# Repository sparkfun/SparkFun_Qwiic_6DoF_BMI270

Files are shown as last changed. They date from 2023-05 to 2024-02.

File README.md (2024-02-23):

SparkFun Qwiic 6DoF BMI270
========================================

<table class="table table-hover table-striped table-bordered">
    <tr align="center">
        <td><a href="https://www.sparkfun.com/products/22397">SparkFun 6DoF IMU Breakout - BMI270 (Qwiic)</a></td>
        <td><a href="https://www.sparkfun.com/products/22398">SparkFun Micro 6DoF IMU Breakout - BMI270 (Qwiic)</a></td>
    </tr>
    <tr align="center">
        <td><i><a href="https://www.sparkfun.com/products/22397">SparkFun 6DoF IMU Breakout - BMI270 (Qwiic)</a></td></i></td>
        <td><i><a href="https://www.sparkfun.com/products/22398">SparkFun Micro 6DoF IMU Breakout - BMI270 (Qwiic)</a></i></td>
    </tr>
</table>

The SparkFun BMI270 6DoF IMU Breakout is a Qwiic-enabled breakout board based on the ultra-low power BMI270 from Bosch. This chip is a highly integrated, low power IMU optimized for wearables providing precise acceleration, angular rate measurement and intelligent on-chip motion-triggered interrupt features.. Not only does the BMI270 comprise a fast and sensitive accelerometer and gyro pair, but it also contains a number of intelligent, on-chip motion-triggered interrupt features.  

Our Standard-sized 1in. x 1in. Qwiic BMI270 IMU Breakout makes it easy to add this sensor to your project using our solderless Qwiic cables and compatible controllers. If you still prefer to use a breadboard, don't worry, we've still broken out all IO pins to 0.1" spaced pin-headers along the sides of the board. On-board solder jumpers allow you to easily select the device address, remove the I²C pull-ups, and disable the power LED if need be. 

Our Micro-sized 0.3in. x 0.75in. footprint makes this breakout board an ideal option for your smallest projects using our solderless Qwiic cables and compatible controllers. On-board solder jumpers allow you to easily select the device address, remove the I²C pull-ups, and disable the power LED if need be. 

The 6-axis sensor combines a 16-bit tri-axial gyroscope and a 16-bit tri-axial accelerometer featuring Bosch’s automotive-proven gyroscope technology. BMI270 includes several functionalities such as an integrated plug-and-play step counter/detector and gesture detection for wrist-worn devices. Moreover, the IMU is suitable for hearables, smart clothes, smart shoes, smart glasses and ankle bands.

Repository Contents
-------------------

* **/Documentation** - Data sheets, additional product information
* **/Hardware** - Eagle design files (.brd, .sch)
* **/Production** - Production panel files (.brd)

Documentation
--------------
* **[Library](https://github.com/sparkfun/SparkFun_BMI270_Arduino_Library)** - Arduino library for the SparkFun 6DoF IMU Breakout - BMI270 (Qwiic) and SparkFun Micro 6DoF IMU Breakout - BMI270 (Qwiic).
* **[Hookup Guide](http://docs.sparkfun.com/SparkFun_Qwiic_6DoF_BMI270/)** - Basic hookup guide for the SparkFun 6DoF IMU Breakout - BMI270 (Qwiic) and SparkFun Micro 6DoF IMU Breakout - BMI270 (Qwiic). 

License Information
-------------------

This product is _**open source**_! 

Please review the LICENSE.md file for license information. 

If you have any questions or concerns on licensing, please contact technical support on our [SparkFun forums](https://forum.sparkfun.com/viewforum.php?f=152).

Distributed as-is; no warranty is given.

- Your friends at SparkFun.

_<COLLABORATION CREDIT>_

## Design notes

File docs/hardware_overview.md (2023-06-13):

###Accelerometer - BMI270

The ultra-low power BMI270 is an IMU optimized for wearables providing precise acceleration, angular rate measurement and intelligent on-chip motion-triggered interrupt features.

The 6-axis sensor combines a 16-bit tri-axial gyroscope and a 16-bit tri-axial accelerometer featuring Bosch’s automotive-proven gyroscope technology. BMI270 includes several functionalities such as an integrated plug-and-play step counter/detector and gesture detection for wrist-worn devices. Moreover, the IMU is suitable for hearables, smart clothes, smart shoes, smart glasses and ankle bands.

<div class="grid.cards.desc" markdown>

<table class="pdf" style="border-style:none;" markdown="1">
<tbody markdown="1">
<tr markdown="1">
<td align="center" width="35%" markdown="block">
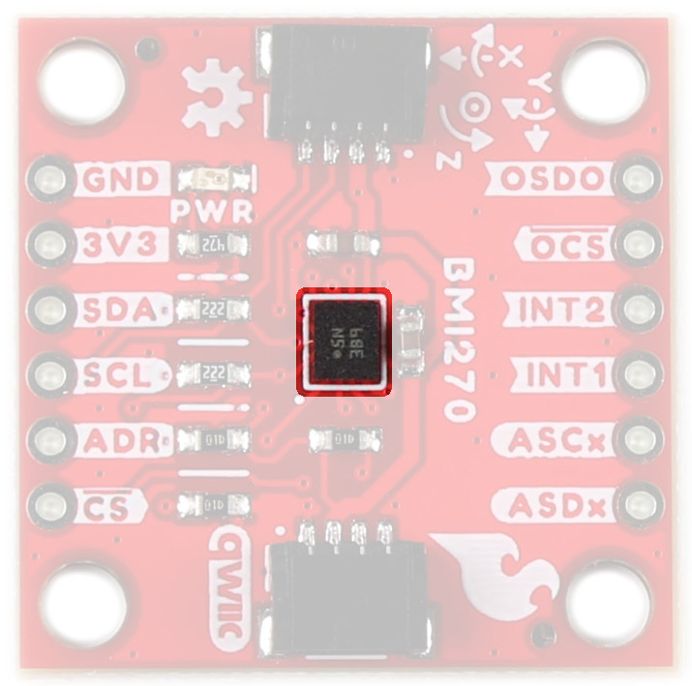
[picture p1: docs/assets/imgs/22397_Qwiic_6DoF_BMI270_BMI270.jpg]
SparkFun 6DoF IMU Breakout - BMI270 (Qwiic)

<figcaption markdown>6DoF BMI270 IC</figcaption>
</td>
<td align="center" width="35%" markdown="block">
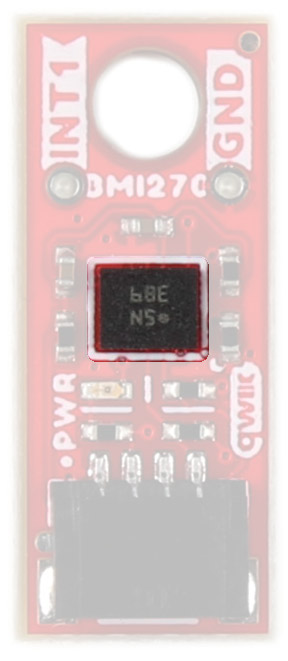
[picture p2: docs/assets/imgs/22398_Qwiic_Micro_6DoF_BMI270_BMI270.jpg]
SparkFun Micro 6DoF IMU Breakout - BMI270 (Qwiic)

<figcaption markdown>Micro 6DoF BMI270 IC</figcaption>
</td>
</tr>
<tr>

</tr>
</tbody>
</table>
</div class>

###Qwiic Connector

The Qwiic connector(s) on the SparkFun 6DoF - BMI270 (Qwiic) and SparkFun 6DoF Micro - BMI270 (Qwiic) provide power and I<sup>2</sup>C connectivity simultaneously.

<div class="grid.cards.desc" markdown>

<table class="pdf" style="border-style:none;" markdown="1">
<tbody markdown="1">
<tr markdown="1">
<td align="center" width="35%" markdown="block">
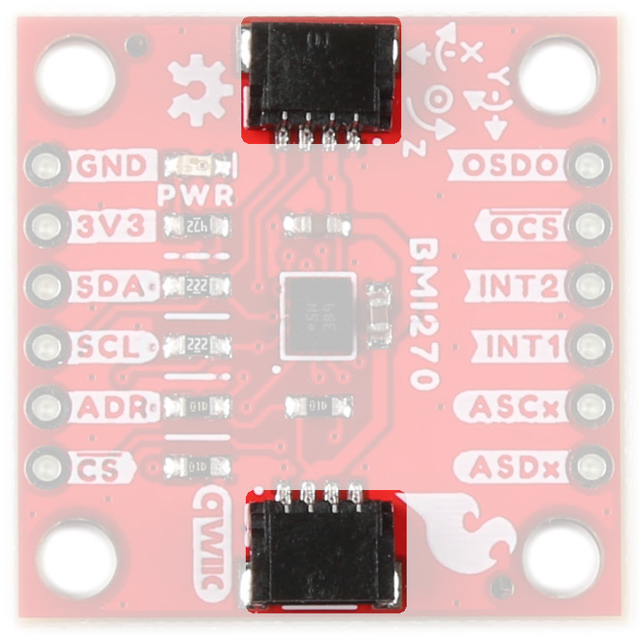
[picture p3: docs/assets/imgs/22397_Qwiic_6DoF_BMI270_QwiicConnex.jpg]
SparkFun 6DoF - BMI270 (Qwiic)

<figcaption markdown>6DoF BMI270 Qwiic Connector</figcaption>
</td>
<td align="center" width="35%" markdown="block">
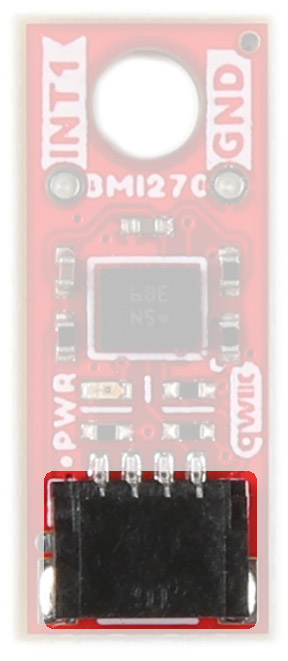
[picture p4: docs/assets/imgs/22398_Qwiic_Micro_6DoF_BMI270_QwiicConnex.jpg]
SparkFun 6DoF Micro - BMI270 (Qwiic)

<figcaption markdown>Micro 6DoF BMI270 Qwiic Connector</figcaption>
</td>
</tr>
</tbody>
</table>
</div class>

###Power

Ideally, power to these boards will be provided by the Qwiic cables. However, should you wish to provide power separately, the 1" x 1" board has its pins broken out to PTH and you can wire up power via these. 

!!! warning
    <p>Make sure to pay attention to logic levels - supply voltage range should be between 1.71V - 3.6V. </p>

<figure markdown>
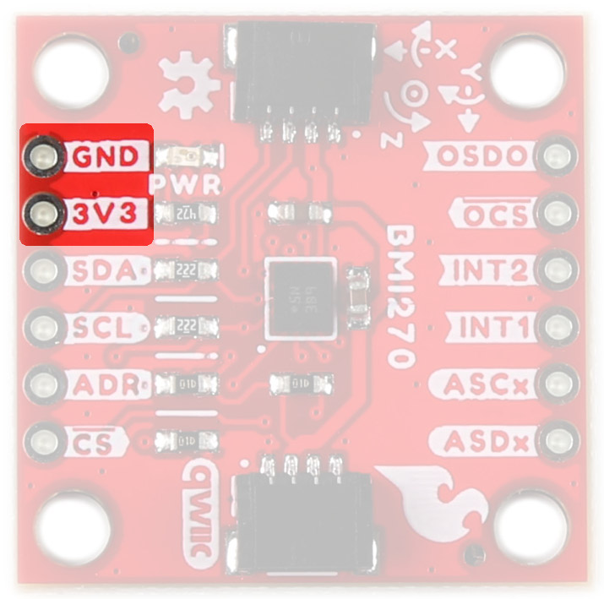
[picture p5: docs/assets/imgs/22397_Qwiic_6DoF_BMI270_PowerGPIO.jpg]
BMI270 Power Pins

<figcaption markdown>BMI270 Power Pins</figcaption>
</figure>

###GPIO

This is a quick overview of the pin functionality. For more information, refer to the [datasheet](assets/BoardFiles/BMI270-Datasheet.pdf).

#### I<sup>2</sup>C

If you do not want to use the Qwiic connectors, I<sup>2</sup>C functionality has been broken out to PTH pins on the 1x1" board. 

<figure markdown>
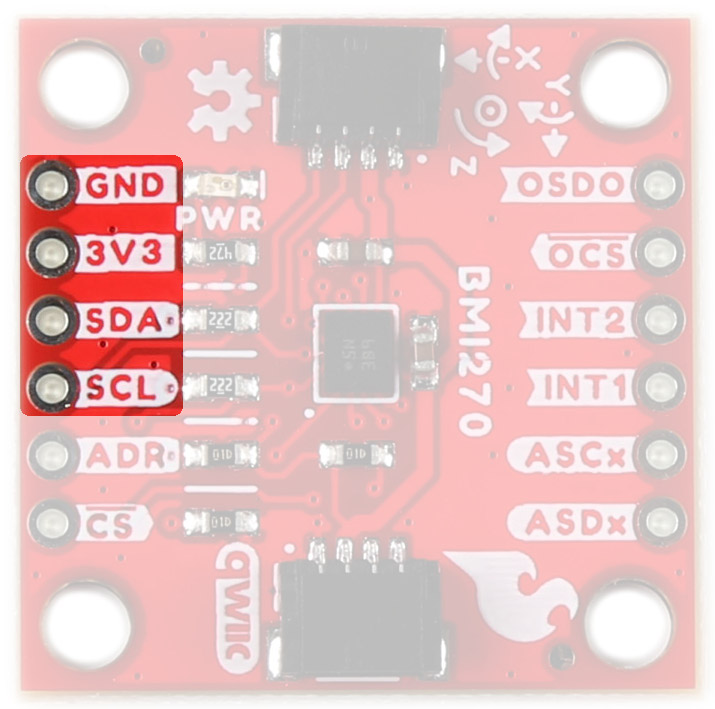
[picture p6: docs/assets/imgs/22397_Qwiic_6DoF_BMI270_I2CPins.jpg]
BMI270 I2C Pins

<figcaption markdown>BMI270 I<sup>2</sup>C Pins</figcaption>
</figure>

#### SPI

Primary SPI functionality has been broken out to the highlighted pins below. 

<figure markdown>
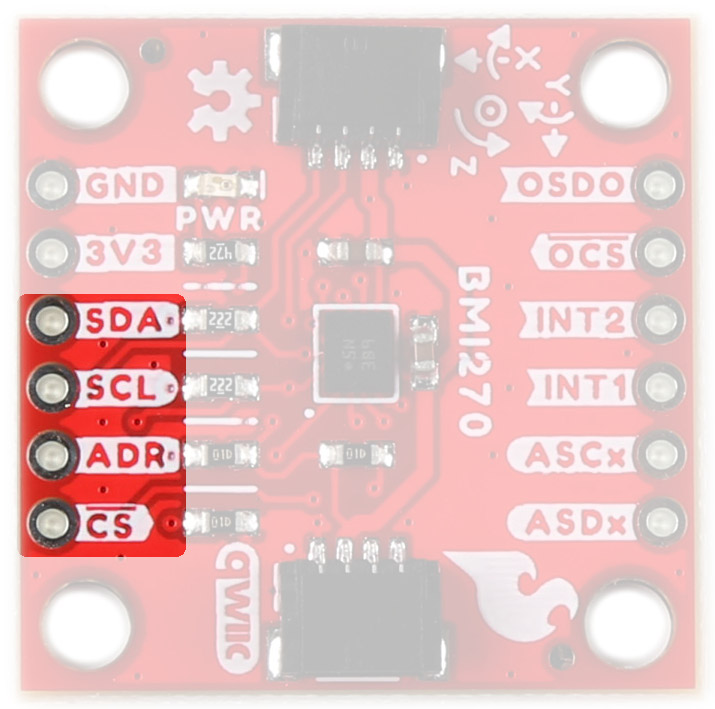
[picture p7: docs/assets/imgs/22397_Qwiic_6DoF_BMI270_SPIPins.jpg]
BMI270 SPI Pins

<figcaption markdown>BMI270 SPI Pins</figcaption>
</figure>

SCL goes to SCK, SDA goes to PICO, ADR goes to POCI, and CS goes to CS

#### Auxiliary Interface 

The ASDx and ASCx pins can be used as a secondary I<sup>2</sup>C interface where an external sensor like a magnetometer can be connected as a peripheral to the device. 

<figure markdown>
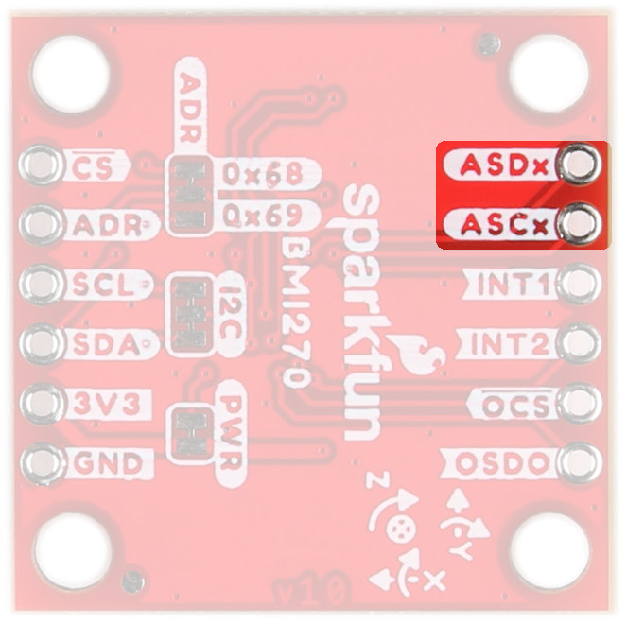
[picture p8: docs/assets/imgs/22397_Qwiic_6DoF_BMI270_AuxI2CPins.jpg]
BMI270 Aux I<sup>2</sup>C Pins

<figcaption markdown>BMI270 Aux I<sup>2</sup>C Pins</figcaption>
</figure>

OSCB and OSDO can act as an auxiliary SPI interface where an external controller can be connected to the device. That can include an external OIS control unit. For more information on implementing the OIS interface, see the [Datasheet](assets/BoardFiles/BMI270-Datasheet.pdf). 

<figure markdown>
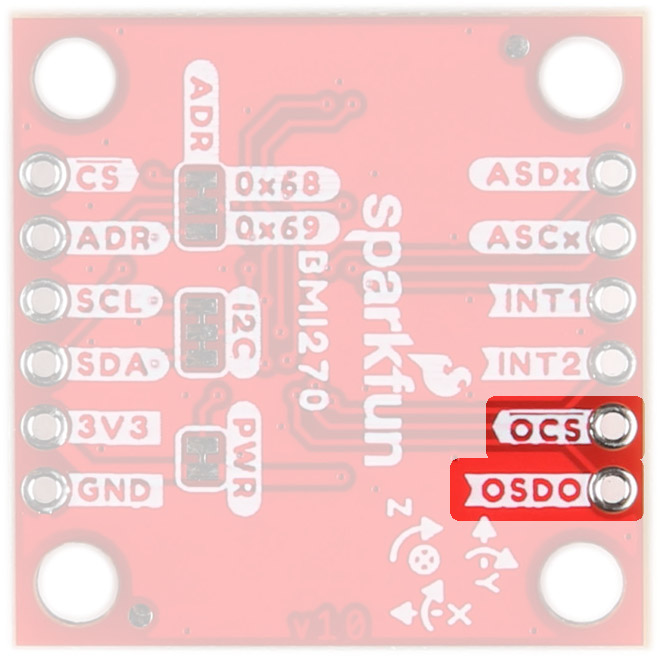
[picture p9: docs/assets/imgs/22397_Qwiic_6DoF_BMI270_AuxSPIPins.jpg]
BMI270 Aux SPI Pins

<figcaption markdown>BMI270 Aux SPI Pins</figcaption>
</figure>

#### Interrupt Pins

Interrupt functionality is available via the INT pins. There are two interrupts available on the 1x1" board, and 1 interrupt available on the Micro. These pins are configurable to be high or low. 

<div class="grid.cards.desc" markdown>

<table class="pdf" style="border-style:none;" markdown="1">
<tbody markdown="1">
<tr markdown="1">
<td align="center" width="35%" markdown="block">
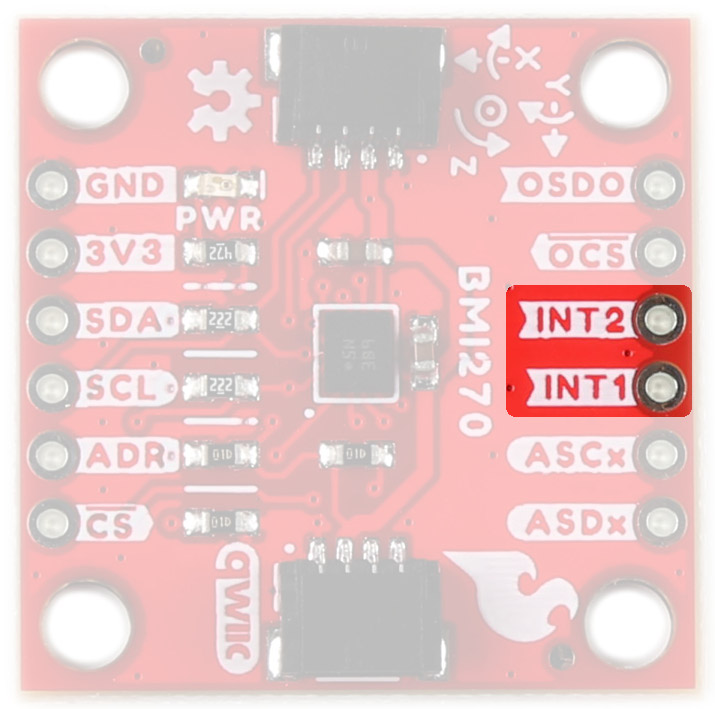
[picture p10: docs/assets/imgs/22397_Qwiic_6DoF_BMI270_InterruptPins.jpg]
BMI270 Interrupt Pins

<figcaption markdown>6DoF BMI270 Interrupt Pins</figcaption>
</td>
<td align="center" width="35%" markdown="block">
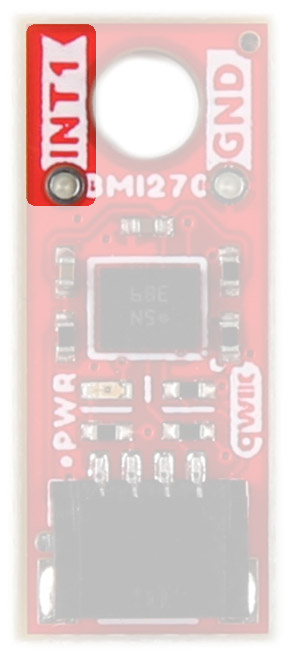
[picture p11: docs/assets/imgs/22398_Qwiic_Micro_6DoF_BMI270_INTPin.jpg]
BMI270 Micro Interrupt Pin

<figcaption markdown>Micro 6DoF BMI270 Interrupt Pin</figcaption>
</td>
</tr>
</tbody>
</table>
</div class>

###Jumpers 

####I2C

Like our other Qwiic boards, the Qwiic 6DoF - BMI270 boards come equipped with pull-up resistors on the clock and data pins. If you are daisy-chaining multiple Qwiic devices, you will want to cut this jumper; if multiple sensors are connected to the bus with the pull-up resistors enabled, the parallel equivalent resistance will create too strong of a pull-up for the bus to operate correctly. As a general rule of thumb, disable all but one pair of pull-up resistors if multiple devices are connected to the bus. To disable the pull up resistors, use an X-acto knife to cut the joint between the two jumper pads highlighted below.

<div class="grid.cards.desc" markdown>

<table class="pdf" style="border-style:none;" markdown="1">
<tbody markdown="1">
<tr markdown="1">
<td align="center" width="35%" markdown="block">
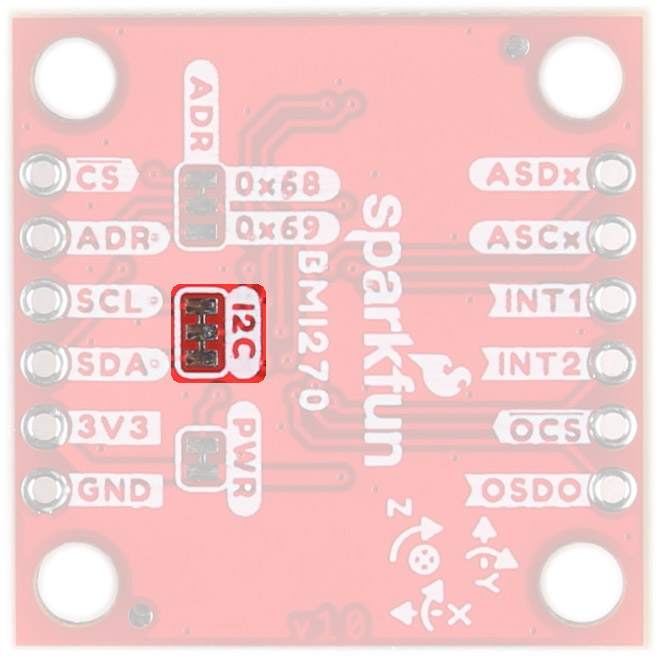
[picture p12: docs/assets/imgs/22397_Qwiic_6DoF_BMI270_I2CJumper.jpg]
SparkFun 6DoF - BMI270 (Qwiic)

<figcaption markdown>6DoF BMI270 I<sup>2</sup>C Jumper</figcaption>
</td>
<td align="center" width="35%" markdown="block">
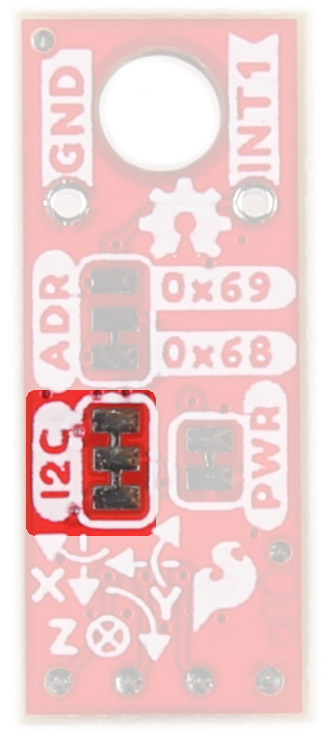
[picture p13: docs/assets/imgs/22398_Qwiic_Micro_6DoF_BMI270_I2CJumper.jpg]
SparkFun 6DoF Micro - BMI270 (Qwiic)

<figcaption markdown>Micro 6DoF BMI270 I<sup>2</sup>C Jumper</figcaption>
</td>
</tr>
</tbody>
</table>
</div class>

####I<sup>2</sup>C Address

The SparkFun 6DoF - BMI270 (Qwiic) boards have a default I<sup>2</sup>C address of 0x68, but by cutting the address jumper on the back of the board, you can select 0x69 (GND) or SPI (fully open). 

0x68 (default) is actually the GND side, 0x69 is the 3.3V side

<div class="grid.cards.desc" markdown>

<table class="pdf" style="border-style:none;" markdown="1">
<tbody markdown="1">
<tr markdown="1">
<td align="center" width="35%" markdown="block">
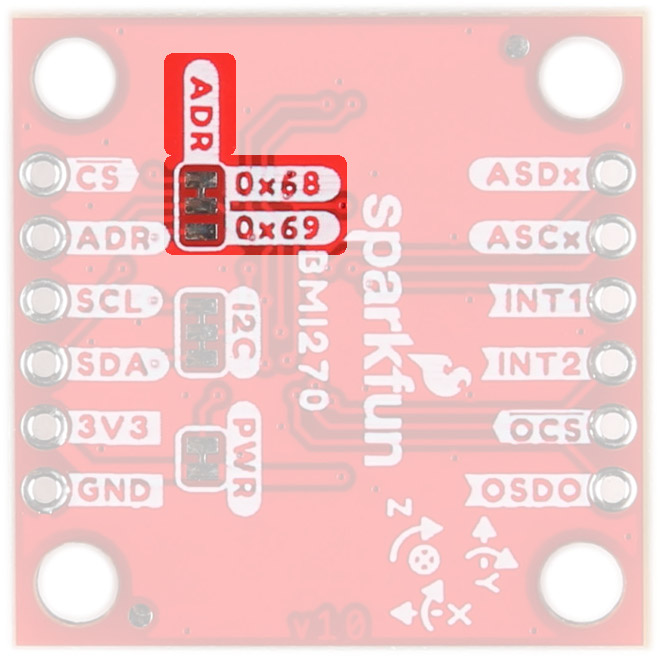
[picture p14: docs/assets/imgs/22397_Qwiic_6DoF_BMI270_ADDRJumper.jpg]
BMI270 Address Jumpers

<figcaption markdown>6DoF BMI270 I<sup>2</sup>C Address Jumper</figcaption>
</td>
<td align="center" width="35%" markdown="block">
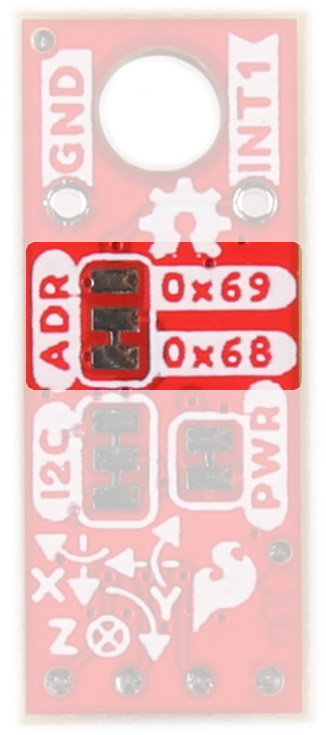
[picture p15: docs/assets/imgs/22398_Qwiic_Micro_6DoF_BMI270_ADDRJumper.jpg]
BMI270 Micro Address Jumpers

<figcaption markdown>Micro 6DoF BMI270 I<sup>2</sup>C Address Jumper</figcaption>
</td>
</tr>
</tbody>
</table>
</div class>

####LED

An LED on the front of each board indicates power is being provided to the board. If you don't like LEDs or you are concerned about current draw, cut the jumper highlighted below. 

<div class="grid.cards.desc" markdown>

<table class="pdf" style="border-style:none;" markdown="1">
<tbody markdown="1">
<tr markdown="1">
<td align="center" width="35%" markdown="block">
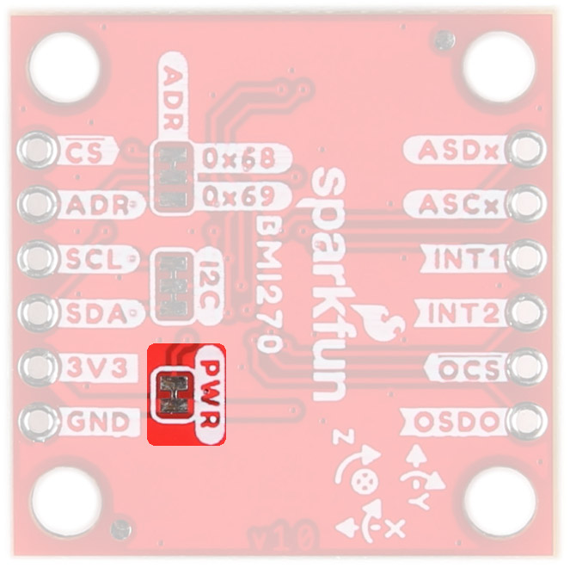
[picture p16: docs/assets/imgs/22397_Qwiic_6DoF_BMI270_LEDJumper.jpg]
SparkFun 6DoF - BMI270 (Qwiic)

<figcaption markdown>6DoF BMI270 LED Jumper</figcaption>
</td>
<td align="center" width="35%" markdown="block">
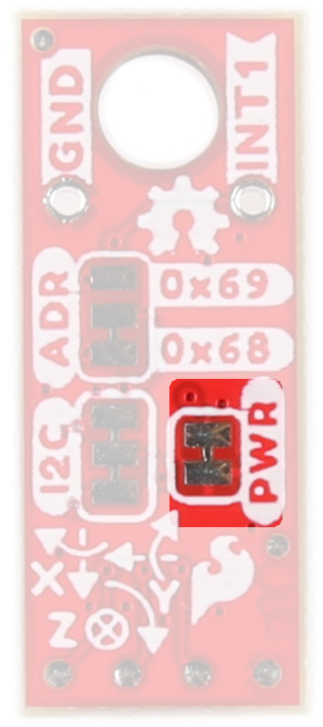
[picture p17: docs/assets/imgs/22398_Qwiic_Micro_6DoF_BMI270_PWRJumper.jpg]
SparkFun 6DoF Micro - BMI270 (Qwiic)

<figcaption markdown>Micro 6DoF BMI270 LED Jumper</figcaption>
</td>
</tr>
</tbody>
</table>
</div class>

###Board Outline

The SparkFun 6DoF - BMI270 (Qwiic) follows the standard 1" x 1" convention of most of our Qwiic breakout boards. 

<figure markdown>
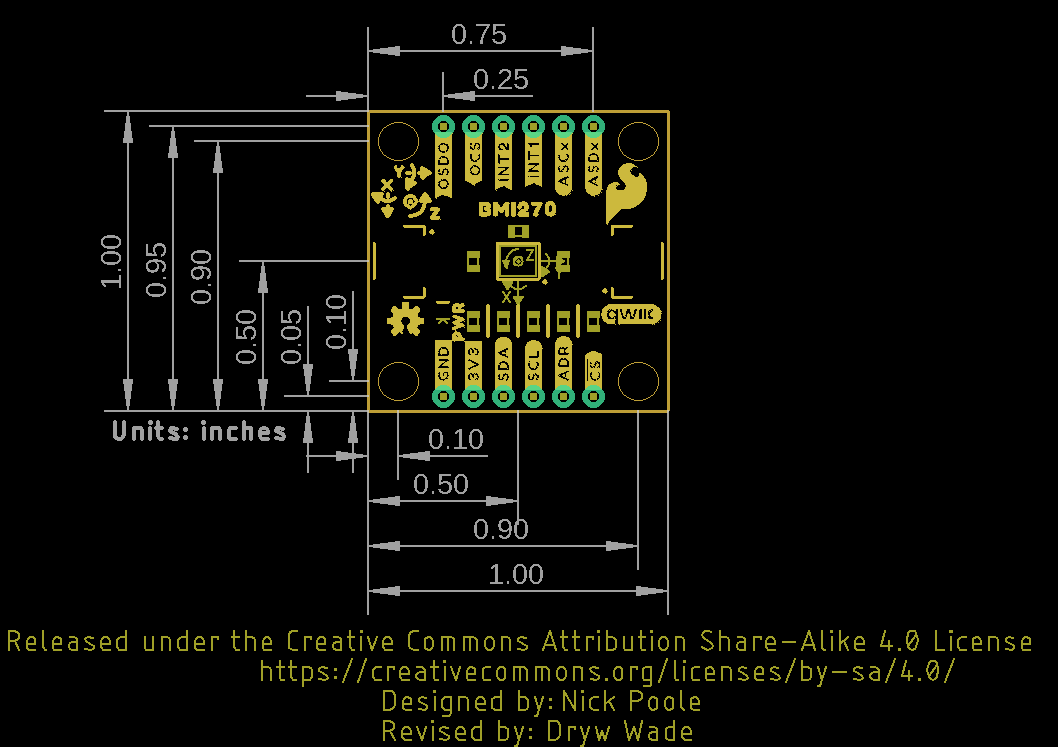
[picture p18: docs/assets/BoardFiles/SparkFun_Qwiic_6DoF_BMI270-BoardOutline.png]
SparkFun 6DoF - BMI270 (Qwiic) Board Outline

<figcaption markdown>SparkFun 6DoF - BMI270 (Qwiic)</figcaption>
</figure>

The SparkFun 6DoF Micro - BMI270 (Qwiic) measures 0.3" x 0.75". 

<figure markdown>
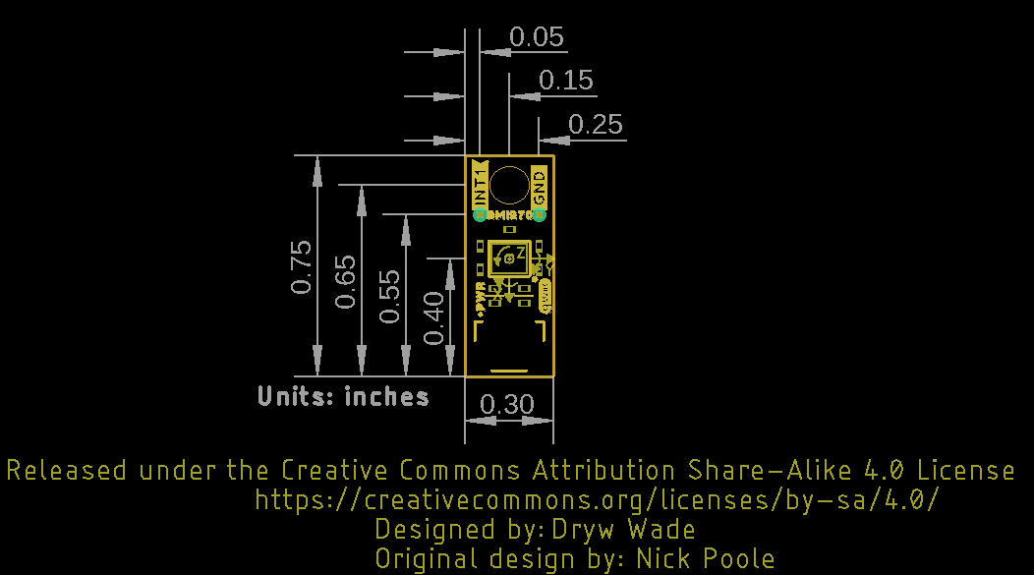
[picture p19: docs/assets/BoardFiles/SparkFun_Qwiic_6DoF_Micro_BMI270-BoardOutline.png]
SparkFun 6DoF - BMI270 (Qwiic) Board Outline

<figcaption markdown>SparkFun 6DoF Micro - BMI270 (Qwiic)</figcaption>
</figure>

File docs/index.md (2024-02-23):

<link rel="stylesheet" href="https://cdnjs.cloudflare.com/ajax/libs/font-awesome/4.7.0/css/font-awesome.min.css">

<div class="grid.cards.desc" markdown>

<table class="pdf" style="border-style:none;" markdown="1">
<tbody markdown="1">
<tr markdown="1">
<td align="center" width="35%" markdown="block">
SparkFun 6DoF IMU Breakout - BMI270 (Qwiic) (https://www.sparkfun.com/products/22397)

The [SparkFun 6DoF IMU Breakout - BMI270 (Qwiic)](https://www.sparkfun.com/products/22397) is a Qwiic enabled board based on the ultra-low power BMI270 from Bosch. This chip is a highly integrated, low power IMU designed for wearable, smart clothing and AR/VR applications. Not only does the BMI270 comprise a fast and sensitive accelerometer and gyro pair, but it also contains a number of intelligent, on-chip motion-triggered interrupt features.  

<center>
[Purchase from SparkFun :fontawesome-solid-cart-plus:](https://www.sparkfun.com/products/22397){ .md-button .md-button--primary }
</center>
</td>
<td align="center" width="35%" markdown="block">
SparkFun Micro 6DoF IMU Breakout - BMI270 (Qwiic) (https://www.sparkfun.com/products/22398)

The [SparkFun Micro 6DoF IMU Breakout - BMI270 (Qwiic)](https://www.sparkfun.com/products/22398) is the 1x1's mini-me, containing most of it's elder sibling's functionality in a tiny little package. 

<center>
[Purchase from SparkFun :fontawesome-solid-cart-plus:](https://www.sparkfun.com/products/22398){ .md-button .md-button--primary }
</center>
</td>
</tr>
</tbody>
</table>
</div class>

### Required Materials

To follow along with this tutorial, you will need the following materials. You may not need everything though depending on what you have. Add it to your cart, read through the guide, and adjust the cart as necessary.

<table style="border-style:none">
    <tr>
        <td>
            <a href="https://www.sparkfun.com/products/22397">
                <center>SparkFun 6DoF IMU Breakout - BMI270 (Qwiic)</center>
                <h3 class="title">SparkFun 6DoF IMU Breakout - BMI270 (Qwiic)</h3>
            </a>
            SEN-22397
        </td>
        <td>
            <a href="https://www.sparkfun.com/products/22398">
                <center>SparkFun Micro 6DoF IMU Breakout - BMI270 (Qwiic)</center>
                <h3 class="title">SparkFun Micro 6DoF IMU Breakout - BMI270 (Qwiic)</h3>
            </a>
            SEN-22398
        </td>
        <td>
            <a href=" https://www.sparkfun.com/products/17259">
                <center>USB micro-B Cable - 6 Foot</center>
                <h3 class="title">Flexible Qwiic Cable - 100mm</h3>
            </a>
            PRT-17259
        </td>
        <td>
            <a href="https://www.sparkfun.com/products/10215">
                <center>USB micro-B Cable - 6 Foot
                </center>
                <h3 class="title">USB micro-B Cable - 6 Foot</h3>
            </a>
            CAB-10215
        </td>
        <td>
            <a href="https://www.sparkfun.com/products/15663">
                <center>SparkFun ESP32 Thing Plus
                </center>
                <h3 class="title">SparkFun ESP32 Thing Plus</h3>
            </a>
            DEV-15663
        </td>
    </tr>
</table>

### Suggested Reading

If you aren’t familiar with the following concepts, we recommend checking out these tutorials before continuing.

<div class="grid cards hide col-4" markdown align="center">

-   <a href="https://learn.sparkfun.com/tutorials/82">
    <figure markdown>
    I2C
    </figure>
    </a>
    <a href="https://learn.sparkfun.com/tutorials/82">**I2C**
    </a>

-   <a href="https://learn.sparkfun.com/tutorials/terminal-basics">
    <figure markdown>
    SPI
    </figure>
    </a>
    <a href="https://learn.sparkfun.com/tutorials/terminal-basics">**Serial Terminal Basics**
    </a>
</div>

<center>
<div align="center">
    <div style="top:5px;left:5px;background-color:Gray;position:relative">
        <div style="top:-5px;left:-5px;background-color:#ffffff;position:relative;border:1px solid black;">
            <a href="https://www.sparkfun.com/qwiic">Qwiic Connect System</a>
        </div>
    </div>
</div>
</center>

The SparkFun 6DoF IMU Breakout - BMI270 (Qwiic) Sensor takes advantage of the [Qwiic connect system](https://www.sparkfun.com/qwiic). We recommend familiarizing yourself with the **Logic Levels** and **I<sup>2</sup>C** tutorials.  Click on the banner above to learn more about [Qwiic products](https://www.sparkfun.com/qwiic).

<center>
    <iframe width="600" height="327" src="https://www.youtube.com/embed/x0RDEHqFIF8" title="SparkFun's Qwiic Connect System" frameborder="0" allow="accelerometer; autoplay; clipboard-write; encrypted-media; gyroscope; picture-in-picture" allowfullscreen></iframe>
</center>

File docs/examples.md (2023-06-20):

The Arduino Library for the SparkFun 6DoF BMI270 (Qwiic) comes with a slew of examples to get you going. Here we'll just look at a few. 

!!! attention
    <p>The BMI270 chip requires an 8kb file to be flashed to memory on the controller. Make sure that whatever controlling board you use, it has enough space. </p>

###Example 1: Basic Readings

This first example just does some basic measurements. To find Example 1, go to **File** > **Examples** > **SparkFun BMI270 Arduino Library** > **Example01_BasicReadingsI2C**:

<figure markdown>
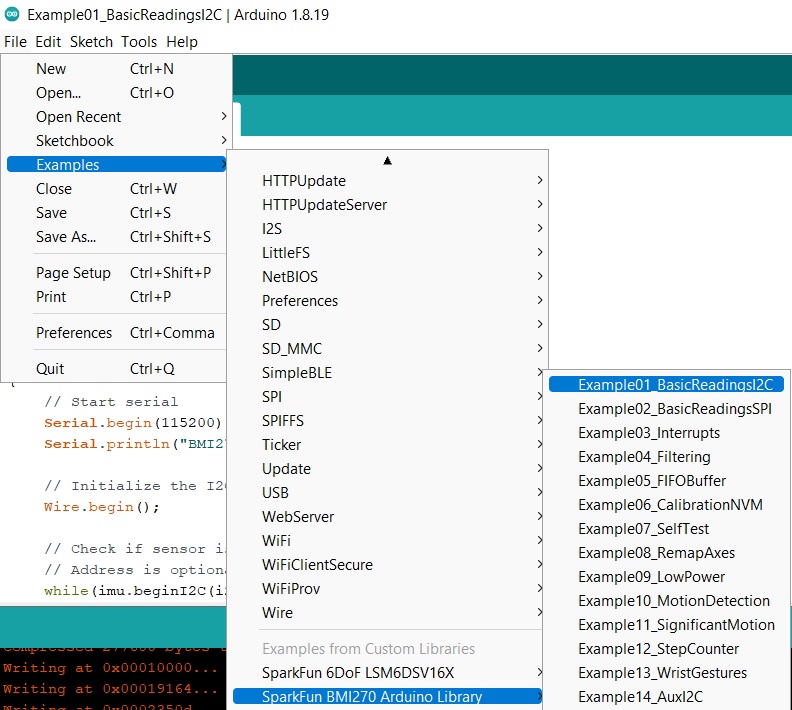
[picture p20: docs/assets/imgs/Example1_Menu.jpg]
BMI270 Arduino Example 1

<figcaption markdown>Finding Example 1</figcaption>
</figure>

Alternatively, you can expand the link below and copy and paste the code into a shiny new Arduino sketch: 

??? "Example 1 Arduino Code"
	```
	--8<-- "https://raw.githubusercontent.com/sparkfun/SparkFun_BMI270_Arduino_Library/main/examples/Example01_BasicReadingsI2C/Example01_BasicReadingsI2C.ino"
	```

Make sure you've selected the correct board and port in the Tools menu and then hit the upload button. Once the code has finished uploading, go ahead and open a [Serial Monitor](https://learn.sparkfun.com/tutorials/terminal-basics). You should see something similar to the following. 

<figure markdown>
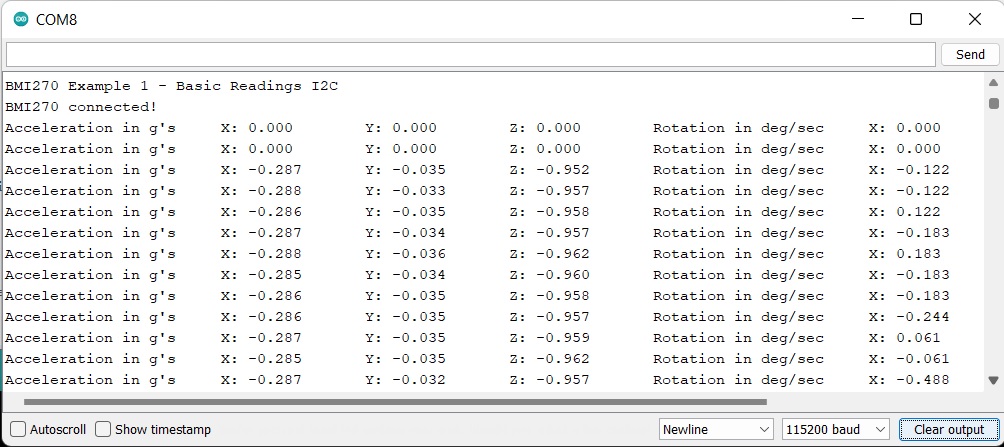
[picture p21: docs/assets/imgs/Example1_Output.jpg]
BMI270 Arduino Example 1 Output

<figcaption markdown>Example 1 Output</figcaption>
</figure>

###Example 6: Calibration to NVM

This example does some basic calibration of the BMI270 and then allows you to write those calibrations to non volatile memory. To find Example 6, go to **File** > **Examples** > **SparkFun BMI270 Arduino Library** > **Example06_CalibrationNVM**. 

<figure markdown>
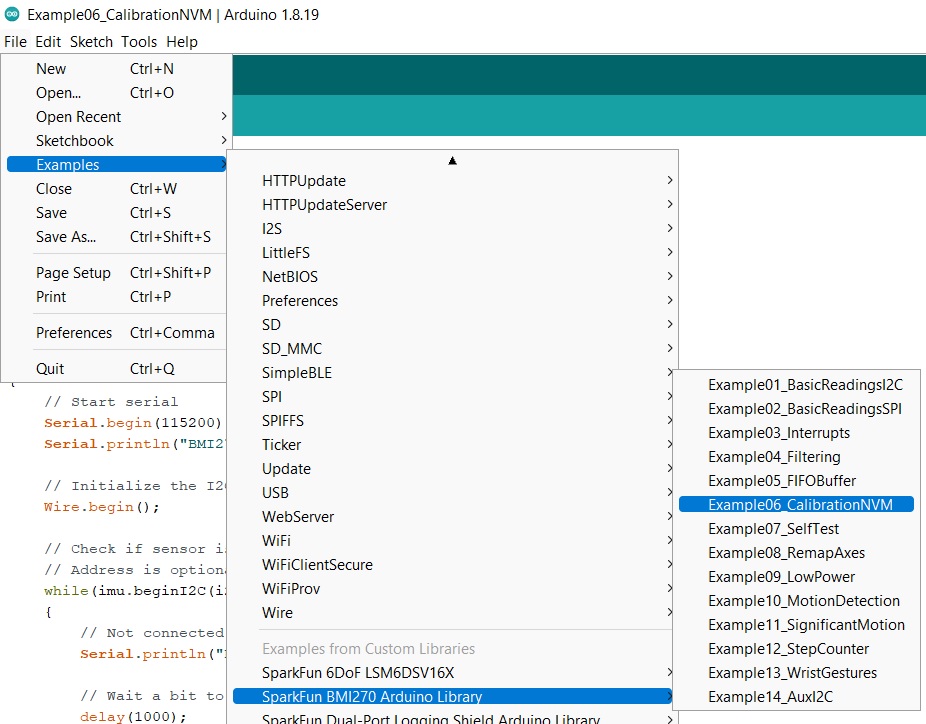
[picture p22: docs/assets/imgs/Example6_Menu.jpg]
BMI270 Arduino Example 6

<figcaption markdown>Finding Example 6</figcaption>
</figure>

Alternatively, you can expand the link below and copy and paste the code into a shiny new Arduino sketch: 

??? "Example 6 Arduino Code"
	```
	--8<-- "https://raw.githubusercontent.com/sparkfun/SparkFun_BMI270_Arduino_Library/main/examples/Example06_CalibrationNVM/Example06_CalibrationNVM.ino"
	```

Again, make sure you've selected the correct board and port in the Tools menu and then hit the upload button. Once the code has finished uploading, go ahead and open a [Serial Monitor](https://learn.sparkfun.com/tutorials/terminal-basics). You should see something similar to the following.

<figure markdown>
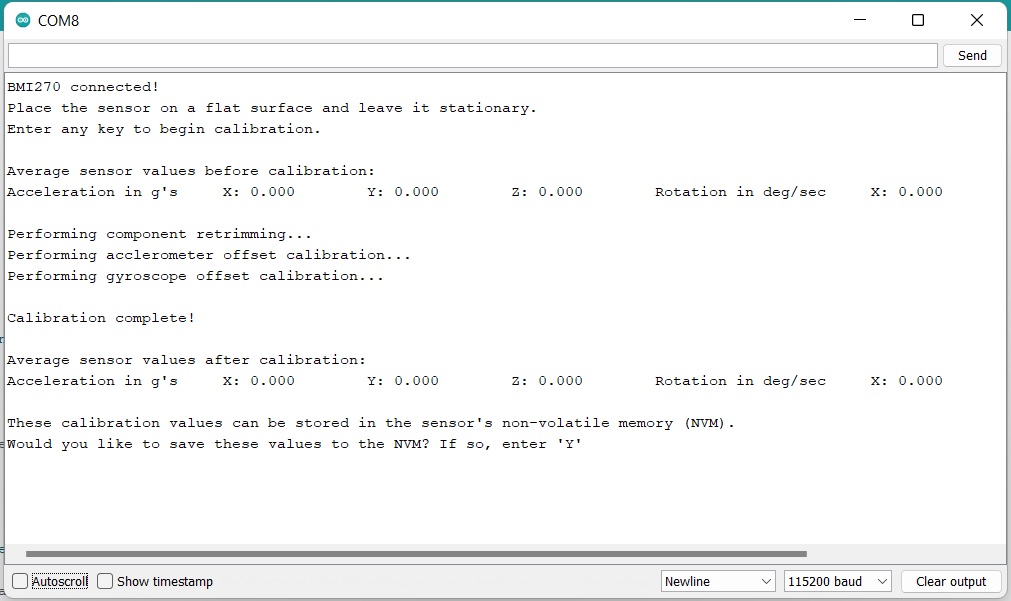
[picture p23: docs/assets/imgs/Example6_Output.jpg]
BMI270 Arduino Example 6 Output

<figcaption markdown>Example 6 Output</figcaption>
</figure>

!!! warning
	This chip only allows a total of 14 writes. Be mindful of this limit when recalibrating. 

###Example 12: Step Counter

 One of the highlights of the BMI270 chip is that it filters out general noise to give you accurate step counts and the like. This example shows the measurements of the BMI270 for walking, running, and when the breakout board is set back down. To find Example 12, go to **File** > **Examples** > **SparkFun BMI270 Arduino Library** > **Example12_StepCounter**:

<figure markdown>
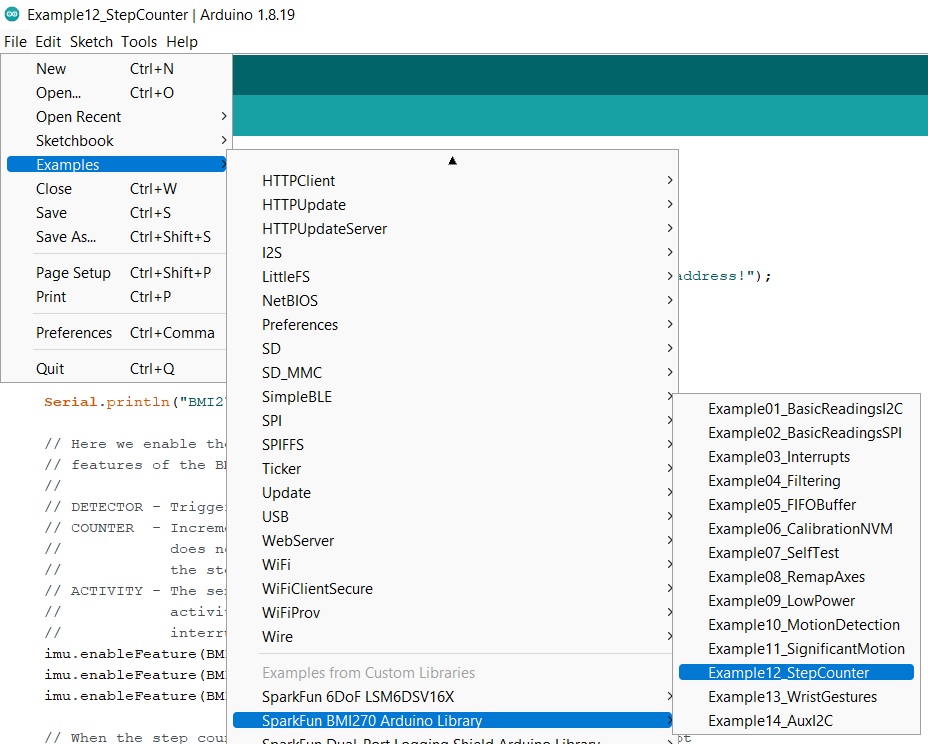
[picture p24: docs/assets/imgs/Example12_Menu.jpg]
BMI270 Arduino Example 12

<figcaption markdown>Finding Example 12</figcaption>
</figure>

Alternatively, you can expand the link below and copy and paste the code into a shiny new Arduino sketch: 

??? "Example 12 Arduino Code"
	```
	--8<-- "https://raw.githubusercontent.com/sparkfun/SparkFun_BMI270_Arduino_Library/main/examples/Example12_StepCounter/Example12_StepCounter.ino"
	```

The wiring for this example is fairly simple. Use the Qwiic connector as normal, and then you'll need to connect your INT1 pin to pin 5/SCK on the ESP32 Thing Plus. Here's what it looks like:

<figure markdown>
BMI270 Arduino Example 12
<figcaption markdown>Example 12</figcaption>
</figure>

Once you get the correct port and board selected and the code is uploaded, you should see something like the following: 

<figure markdown>
BMI270 Arduino Example 12 Output
<figcaption markdown>Example 12 Output</figcaption>
</figure>

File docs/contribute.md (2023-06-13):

# Contribute: Make an Augmentation!
Spot an improvement opportunity? Feel free to contribute to our open-source design and documentation. 

## :material-file-document-multiple:&nbsp;Improve our Documentation
All of this documentation can be modified by you! Please help us make it better.

* These pages are contained in the [`docs` folder](https://github.com/sparkfun/SparkFun_Qwiic_6DoF_BMI270/tree/main/docs) of the [SparkFun 6DoF - BMI270 (Qwiic) repository](https://github.com/sparkfun/SparkFun_Qwiic_6DoF_BMI270).

### Submit a Correction

1. With a GitHub account, [fork this repository](https://github.com/sparkfun/SparkFun_Qwiic_6DoF_BMI270/fork).
2. Add your corrections or improvements to the markdown file.
3. File a pull request with your changes, and enjoy making the ~~words~~ ~~worlds~~ world a better place.
	* Once received, the documentation specialist will automatically be notified.
	* We will review your suggested improvements to make sure they are correct and fit within our documentation standards.

## :material-cog:&nbsp;Improve our Hardware Design
All of our designs are open-source! Please help us make it better.

* Our board design files are contained in the [`Hardware` folder](https://github.com/sparkfun/SparkFun_Qwiic_6DoF_BMI270/tree/main/Hardware) of the [SparkFun Qwiic 6DoF BMI270 repository](https://github.com/sparkfun/SparkFun_Qwiic_6DoF_BMI270).

1. With a GitHub account, [fork this repository](https://github.com/sparkfun/SparkFun_Qwiic_6DoF_BMI270/fork).
2. Add your design augmentation(s)
3. File a pull request with your changes, and enjoy making the ~~words~~ ~~worlds~~ world a better place.
	1. Once received, the engineer in charge of the original design will automatically be notified.
	2. We will review your suggested improvement(s) to verify that they are within our board design standards and meet our product design requirements.
	3. If approved, we will flag these changes for our next board revision. Congrats! 🍻

		!!! info
			Even if your suggestion is accepted, these changes may not be immediately available for purchase. We may have to cycle through our current product inventory first.

## Contributors&nbsp;:clap:
Let's provide some recognition to the contributors for this project!

GitHub Contributors Image
<br>


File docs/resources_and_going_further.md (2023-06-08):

For more information, check out the resources below.

SparkFun 6DoF BMI270 1"x1" Board: 

* [Schematic (PDF)](assets/BoardFiles/SparkFun_Qwiic_6DoF_BMI270-Schematic.pdf){:target="_blank"}
* [Eagle Files](assets/BoardFiles/SparkFun_Qwiic_6DoF_BMI270-EagleFiles.zip)
* [Board Outline (PNG)](assets/BoardFiles/SparkFun_Qwiic_6DoF_BMI270-BoardOutline.png){:target="_blank"}
* [GitHub Hardware Repo](https://github.com/sparkfun/SparkFun_Qwiic_6DoF_BMI270){:target="_blank"}

SparkFun 6DoF BMI270 Micro Board: 

* [Schematic (PDF)](assets/BoardFiles/SparkFun_Qwiic_6DoF_Micro_BMI270-Schematic.pdf){:target="_blank"}
* [Eagle Files](assets/BoardFiles/SparkFun_Qwiic_6DoF_Micro_BMI270-EagleFiles.zip)
* [Board Outline (PNG)](assets/BoardFiles/SparkFun_Qwiic_6DoF_Micro_BMI270-BoardOutline.png){:target="_blank"}
* [GitHub Hardware Repo](https://github.com/sparkfun/SparkFun_Qwiic_6DoF_BMI270){:target="_blank"}

Or check out other [Qwiic Sensor Tutorials](https://learn.sparkfun.com/tutorials/tags/qwiic):

<table style="border-style:none">
    <tr>
        <td style="vertical-align: text-top;" width="264px">
            <a href="https://learn.sparkfun.com/tutorials/sparkfun-humidity-sensor-breakout---shtc3-qwiic-hookup-guide">
            
            <h3 style="vertical-align: left">SparkFun Humidity Sensor Breakout - SHTC3 (Qwiic) Hookup Guide
            </h3></a>
        </td>
        <td style="vertical-align: text-top;" width="264px">
            <div style="text-align: center"><a href="https://learn.sparkfun.com/tutorials/qwiic-atmospheric-sensor-bme280-hookup-guide">
            </div>
            <h3 style="text-align: left">Qwiic Atmospheric Sensor (BME280) Hookup Guide
            </h3></a>
        </td>
        <td style="vertical-align: text-top;" width="264px">
            <div style="text-align: center"><a href="https://learn.sparkfun.com/tutorials/qwiic-tmp117-high-precision-digital-temperature-sensor-hookup-guide">
            </div>
            <h3 style="text-align: left">Qwiic TMP117 High Precision Digital Temperature Sensor Hookup Guide
            </h3></a>
        </td>
        <td style="vertical-align: text-top;" width="264px">
            <a href="https://learn.sparkfun.com/tutorials/qwiic-pressure-sensor-bmp384-hookup-guide">
            
            <h3 style="text-align: left">Qwiic Pressure Sensor (BMP384) Hookup Guide
            </h3></a>
        </td>
    </tr>
</table>

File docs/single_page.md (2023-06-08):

---
hide:
  - navigation
  - toc
icon: fontawesome/solid/scroll
---

# Introduction
--8<-- "./docs/index.md"

# Hardware Overview
--8<-- "./docs/hardware_overview.md"

# Hardware Assembly
--8<-- "./docs/hardware_assembly.md"

# Software Setup and Programming
--8<-- "./docs/software_setup_and_programming.md"

# Arduino Examples
--8<-- "./docs/examples.md"

# Troubleshooting
--8<-- "./docs/troubleshooting.md"

# Resources:
--8<-- "./docs/resources.md"

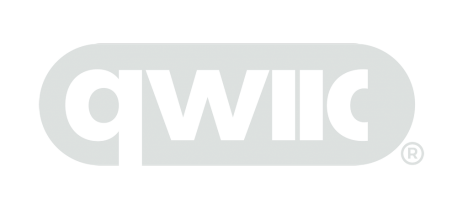
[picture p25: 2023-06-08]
docs/assets/imgs/Qwiic-registered-white.png

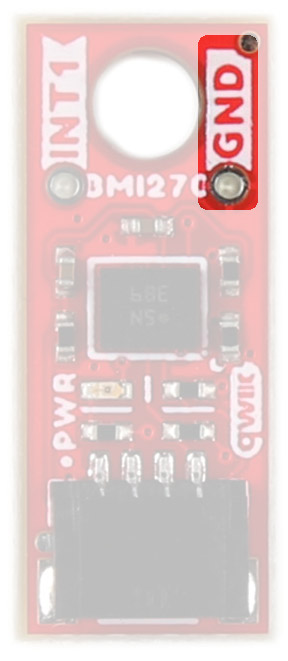
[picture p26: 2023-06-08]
docs/assets/imgs/22398_Qwiic_Micro_6DoF_BMI270_GNDPin.jpg

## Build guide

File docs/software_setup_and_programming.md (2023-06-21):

!!! attention
	If this is your first time using Arduino, please review our tutorial on [installing the Arduino IDE](https://learn.sparkfun.com/tutorials/installing-arduino-ide). If you have not previously installed an Arduino library, please check out our [installation guide](https://learn.sparkfun.com/tutorials/installing-an-arduino-library).

SparkFun has written a library to work with the SparkFun Qwiic 6DoF BMI270 Boards. You can obtain this library through the Arduino Library Manager by searching for "BMI270" and installing the latest version. If you prefer downloading libraries manually, you can grab them from the GitHub Repository.

<center>
	[SparkFun Qwiic 6DoF BMI270 Arduino Library GitHub](https://github.com/sparkfun/SparkFun_BMI270_Arduino_Library/archive/refs/heads/main.zip){ .md-button .md-button--primary }
</center>

!!! attention
	Optical Image Stabilization (OIS) has not been implemented in this library. If you wish to use this functionality, please refer to the [datasheet](assets/BoardFiles/BMI270-Datasheet.pdf){:target="_blank"}.

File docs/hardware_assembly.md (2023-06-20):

The delightful thing about our Qwiic boards is that they are quite literally plug and play. 

<figure markdown>
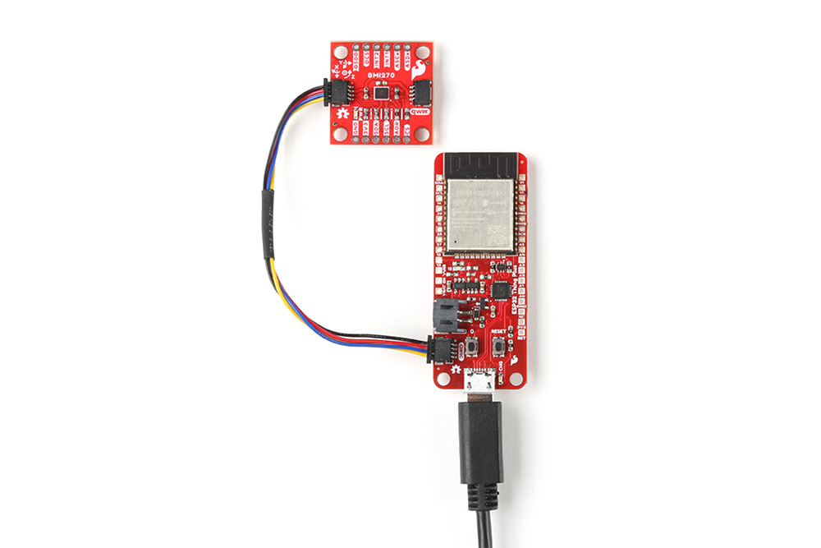
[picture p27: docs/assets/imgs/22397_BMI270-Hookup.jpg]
SparkFun 6DoF IMU Breakout - BMI270 (Qwiic) Plugged into the ESP32 Thing Plus

<figcaption markdown>SparkFun 6DoF IMU Breakout - BMI270 (Qwiic) Plugged into the ESP32 Thing Plus</figcaption>
</figure>

<figure markdown>
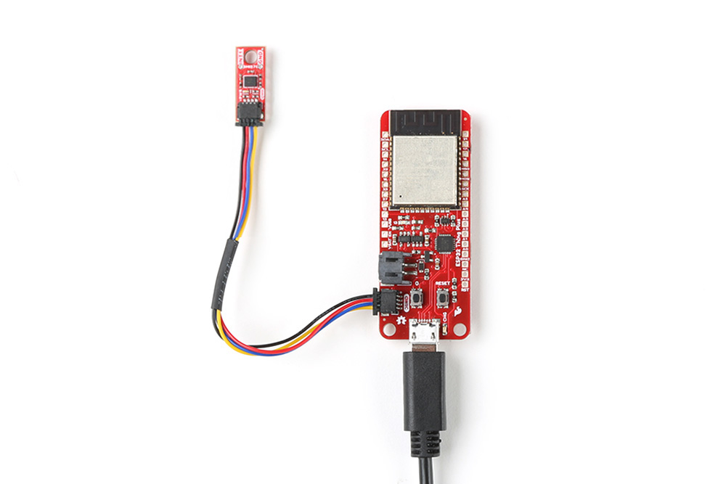
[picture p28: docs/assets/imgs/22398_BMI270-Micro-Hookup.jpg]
SparkFun Micro 6DoF IMU Breakout - BMI270 (Qwiic) Plugged the ESP32 Thing Plus

<figcaption markdown>SparkFun Micro 6DoF IMU Breakout - BMI270 (Qwiic) Plugged into the ESP32 Thing Plus</figcaption>
</figure>

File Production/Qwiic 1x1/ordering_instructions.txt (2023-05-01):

panel size, 169x117mm
PCB thickness, 1.6mm
number of layers, 2
soldermask color, Red
silkscreen color, White
oz copper, 1oz
finish, HASL lead free
stencils, top
pcs per panel, 24
min trace width, 0.2540mm / 0.0100in
min drill size, 0.3048mm / 0.0120in

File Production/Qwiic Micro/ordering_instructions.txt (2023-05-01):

panel size, 79x170mm
PCB thickness, 1.6mm
number of layers, 2
soldermask color, Red
silkscreen color, White
oz copper, 1oz
finish, HASL lead free
stencils, top
pcs per panel, 64
min trace width, 0.1270mm / 0.0050in
min drill size, 0.3048mm / 0.0120in

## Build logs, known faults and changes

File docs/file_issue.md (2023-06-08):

# Did we make a mistake?

Spot something wrong? Please let us know. 

!!! attention
    This is not where customers should seek assistance on a product. If you require technical assistance or have questions about a product that is not working as expected, please head over to the [SparkFun Technical Assistance](https://www.sparkfun.com/technical_assistance) page for some initial troubleshooting.
    <center>
    [SparkFun Technical Assistance Page](https://www.sparkfun.com/technical_assistance){ .md-button .md-button--primary }
    </center>
    
    If you can't find what you need there, you'll need a [Forum Account](https://forum.sparkfun.com/ucp.php?mode=register) to search product forums and post questions.

## Discrepancies in the Documentation

All of this documentation can be modified by you! Please help us make it better.

* The documentation files for these pages are contained in the [`docs` folder](https://github.com/sparkfun/SparkFun_Qwiic_6DoF_BMI270/tree/main/docs) of the [SparkFun 6DoF IMU Breakout - BMI270 (Qwiic)](https://github.com/sparkfun/SparkFun_Qwiic_6DoF_BMI270) repository.

### Spot something wrong?
If a section of the documentation is incorrect, please [open an issue](https://github.com/sparkfun/SparkFun_Qwiic_6DoF_BMI270/issues) and let us know.

### Do you have a suggested correction?
1. With a GitHub account, fork this repo
2. Add your correction(s) or improvement(s) to the markdown file(s)
3. File a pull request with your changes, and enjoy making the ~~words~~ ~~worlds~~ world a better place.
    * Once received, the documentation specialist will automatically be notified.
    * We will review your suggested improvement(s) to make sure they are correct and fit within our documentation standards.

## Problems in the Hardware Design

All of our designs are open-source! Please help us make it better.

* Our board design files are contained in the [`Hardware` folder](https://github.com/sparkfun/SparkFun_Qwiic_6DoF_BMI270/tree/main/Hardware) of the [SparkFun 6DoF IMU Breakout - BMI270 (Qwiic)](https://github.com/sparkfun/SparkFun_Qwiic_6DoF_BMI270) repository. 

### Does something not make sense?
If part of the design is confusing, please [open an issue](https://github.com/sparkfun/SparkFun_Qwiic_6DoF_BMI270/issues) and let us know.

### Did we forget to include an important function of the board?
* Please keep in mind that we may intentionally exclude certain functions of the board to meet our product design requirements. *(For example, our Qwiic Micro boards are intended to fit on a small board layout and only use I<sup>2</sup>C communication; therefore, we may not have the SPI and interrupt pins available for users.)*
* If part of the board's functionality is missing, please [open an issue](https://github.com/sparkfun/SparkFun_Qwiic_6DoF_BMI270/issues) and file a feature request.

### Do you wish to contribute directly to improving the board design?
1. With a GitHub account, Fork this repo
2. Add your design improvement(s)
3. File a pull request with your changes, and enjoy making the ~~words~~ ~~worlds~~ world a better place.
    * Once received, the engineer in charge of the original design will automatically be notified.
    * We will review your suggested improvement(s), if they are within our board design standards and meet our product design requirements, we will flag these changes for our next board revision. *(Please note, that even if your suggestion is accepted, these changes may not be immediate. We may have to cycle through our current product inventory first.)*

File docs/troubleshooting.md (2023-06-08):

!!! note
    <span class="glyphicon glyphicon-question-sign" aria-hidden="true"></span>
        <strong> Not working as expected and need help? </strong> <br /><br />

    If you need technical assistance and more information on a product that is not working as you expected, we recommend heading on over to the <a href="https://www.sparkfun.com/technical_assistance">SparkFun Technical Assistance</a> page for some initial troubleshooting. <br /><br />

    <div style="text-align: center"><a href="https://www.sparkfun.com/technical_assistance" target="sfe_technical_assistance" class="md-button">SparkFun Technical Assistance Page</a></div>

    If you don't find what you need there, the <a href="https://forum.sparkfun.com/index.php">SparkFun Forums</a> are a great place to find and ask for help. If this is your first visit, you'll need to <a href="https://forum.sparkfun.com/ucp.php?mode=register">create a Forum Account</a> to search product forums and post questions.<br /><br />

    <div style="text-align: center"><a href="https://forum.sparkfun.com/ucp.php?mode=register" class="md-button">Create New Forum Account</a>&nbsp;&nbsp;&nbsp;<a href="https://forum.sparkfun.com/index.php" class="md-button md-button--primary">Log Into SparkFun Forums</a></div>

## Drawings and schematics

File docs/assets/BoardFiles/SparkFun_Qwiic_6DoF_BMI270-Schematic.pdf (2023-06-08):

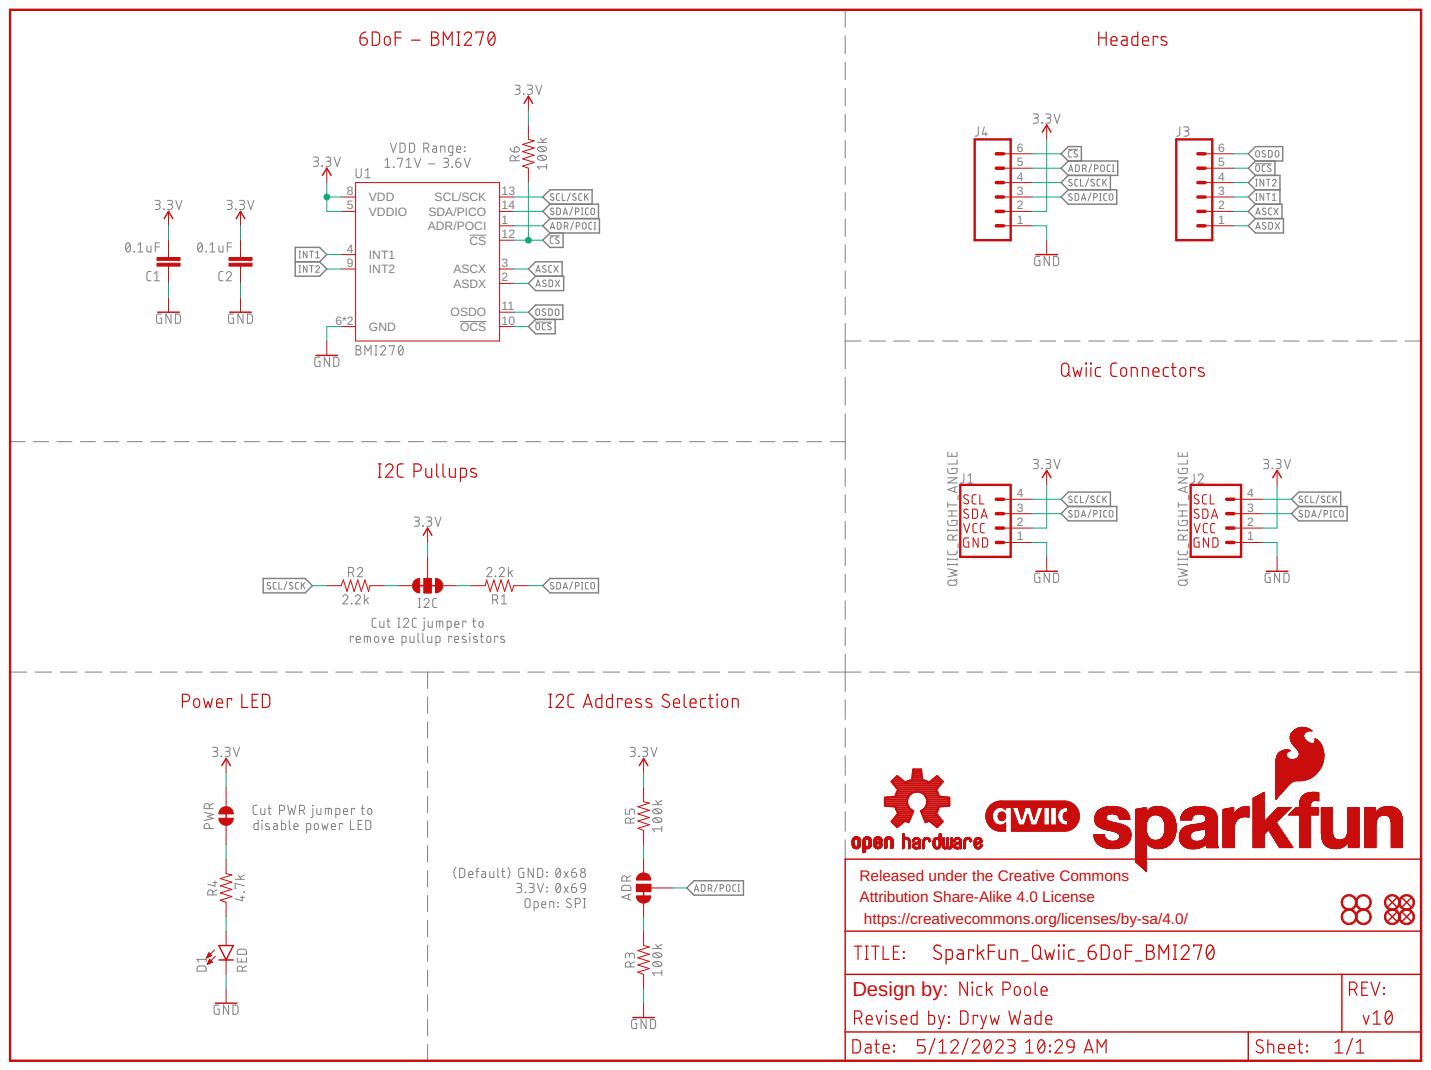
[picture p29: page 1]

Released under the Creative Commons Attribution Share-Alike 4.0 License

https://creativecommons.org/licenses/by-sa/4.0/

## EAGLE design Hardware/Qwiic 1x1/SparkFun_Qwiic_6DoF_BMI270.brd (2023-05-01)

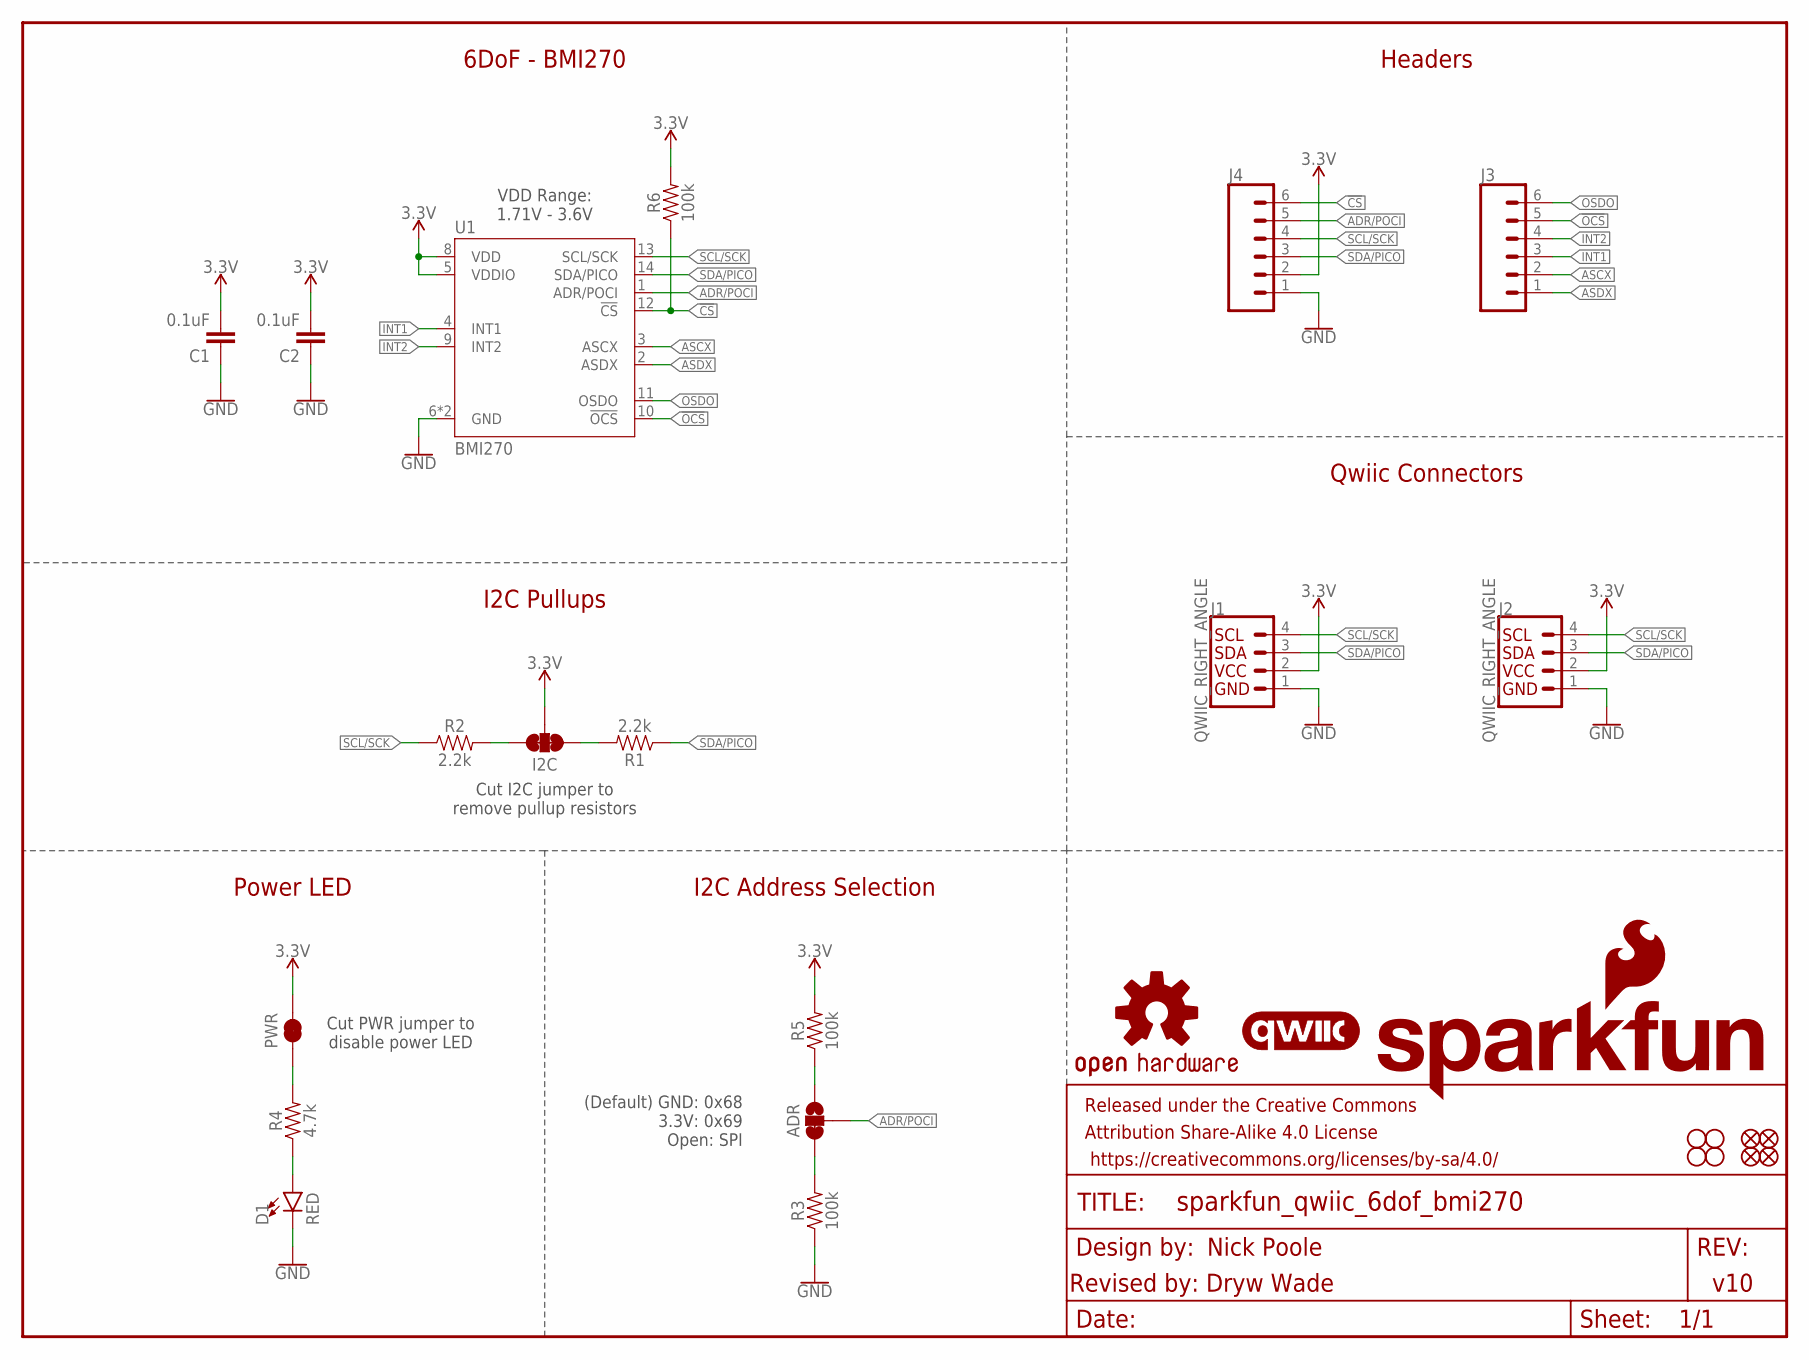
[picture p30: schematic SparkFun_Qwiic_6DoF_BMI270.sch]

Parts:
ADR: JUMPER-SMT_3_1-NC_TRACE_SILK; SMT-JUMPER_3_1-NC_TRACE_SILK
C1, C2: 0.1uF; 0603
D1: RED; LED-0603
FD1, FD2, FD3, FD4: FIDUCIAL1X2; FIDUCIAL-1X2
FRAME1: FRAME-LETTER; CREATIVE_COMMONS
H1, H2, H3, H4: STAND-OFF
I2C: JUMPER-SMT_3_2-NC_TRACE_SILK; SMT-JUMPER_3_2-NC_TRACE_SILK
J1, J2: QWIIC_RIGHT_ANGLE; JST04_1MM_RA
J3, J4: CONN_06NO_SILK_NO_POP; 1X06_NO_SILK
LOGO1: SFE_LOGO_NAME_FLAME.1_INCH; SFE_LOGO_NAME_FLAME_.1
LOGO2: QWIIC_LOGO_5MM; QWIIC_5MM
LOGO3: OSHW-LOGOS; OSHW-LOGO-S
PWR: JUMPER-SMT_2_NC_TRACE_SILK; SMT-JUMPER_2_NC_TRACE_SILK
R1, R2: 2.2k; 0603
R3, R5, R6: 100k; 0603
R4: 4.7k; 0603
U1: BMI270

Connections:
3.3V: C1.2, C2.2, I2C.2, J1.2, J2.2, J4.2, PWR.2, R5.2, R6.2, U1.5 (VDDIO), U1.8 (VDD)
!CS!: J4.6, R6.1, U1.12 (!CS!)
!OCS!: J3.5, U1.10 (!OCS!)
ADR/POCI: ADR.2, J4.5, U1.1 (ADR/POCI)
ASCX: J3.2, U1.3 (ASCX)
ASDX: J3.1, U1.2 (ASDX)
GND: C1.1, C2.1, D1.C, J1.1, J2.1, J4.1, R3.1, U1.6 (GND), U1.7 (GND)
INT1: J3.3, U1.4 (INT1)
INT2: J3.4, U1.9 (INT2)
unnamed: I2C.1, R1.2
unnamed: I2C.3, R2.2
unnamed: PWR.1, R4.2
unnamed: D1.A, R4.1
unnamed: ADR.1, R5.1
unnamed: ADR.3, R3.2
OSDO: J3.6, U1.11 (OSDO)
SCL/SCK: J1.4, J2.4, J4.4, R2.1, U1.13 (SCL/SCK)
SDA/PICO: J1.3, J2.3, J4.3, R1.1, U1.14 (SDA/PICO)

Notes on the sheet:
(Default) GND: 0x68 3.3V: 0x69 Open: SPI
Cut PWR jumper to disable power LED
Power LED
Headers
Qwiic Connectors
Nick Poole
Revised by: Dryw Wade
v10
6DoF - BMI270
Cut I2C jumper to remove pullup resistors
VDD Range: 1.71V - 3.6V
I2C Address Selection
I2C Pullups

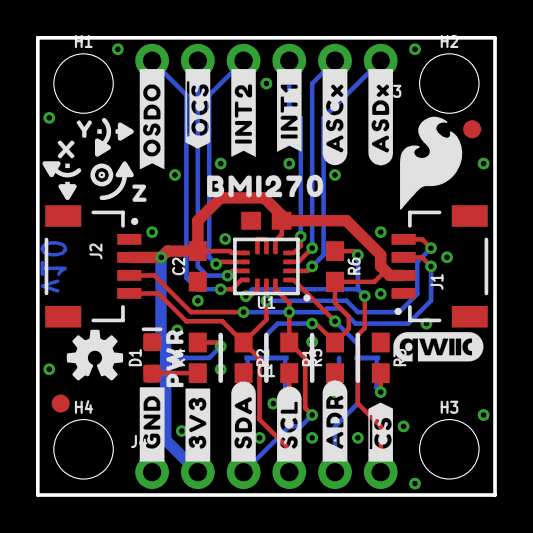
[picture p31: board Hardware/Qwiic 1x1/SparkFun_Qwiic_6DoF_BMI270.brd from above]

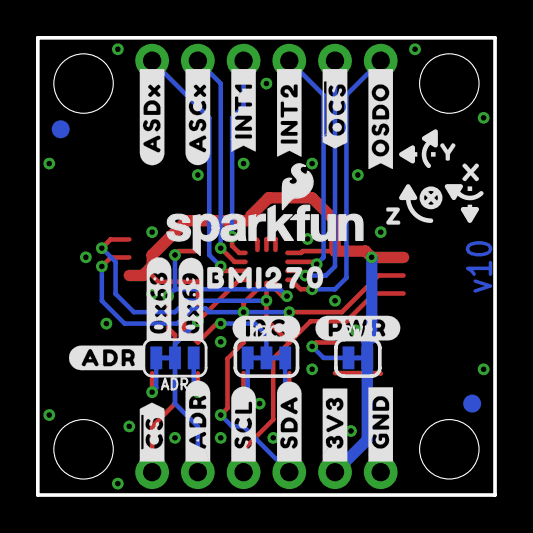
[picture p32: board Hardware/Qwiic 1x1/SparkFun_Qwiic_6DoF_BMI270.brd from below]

Board: 2 copper layers, 25.4 x 25.4 mm, 69 parts (27 on the bottom side), 18 nets.

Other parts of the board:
U$1: #I2C#0
U$2, U$14: #_SDA#0
U$3: SFE_LOGO_FLAME_.2
U$4: #PWR#0
U$5: #ADR#0
U$6: #0X68#0
U$7, U$13: #_3V3#0
U$8, U$17: #_#CS##0
U$9, U$16: #_ADR#0
U$10, U$15: #_SCL#0
U$11, U$27: #ASDX_#0
U$12, U$19: #_GND#0
U$18: #0X69#0
U$20, U$21: BMI2700
U$22, U$28: #ASCX_#0
U$23, U$29: #INT1_#0
U$24, U$30: #INT2_#0
U$25, U$31: ##OCS#_#0
U$26, U$32: #OSDO_#0
U$33: ORDERING_INSTRUCTIONS
U$34: PWR0
U$79, U$88: X0
U$80, U$89: Y0
U$81, U$90: Z0

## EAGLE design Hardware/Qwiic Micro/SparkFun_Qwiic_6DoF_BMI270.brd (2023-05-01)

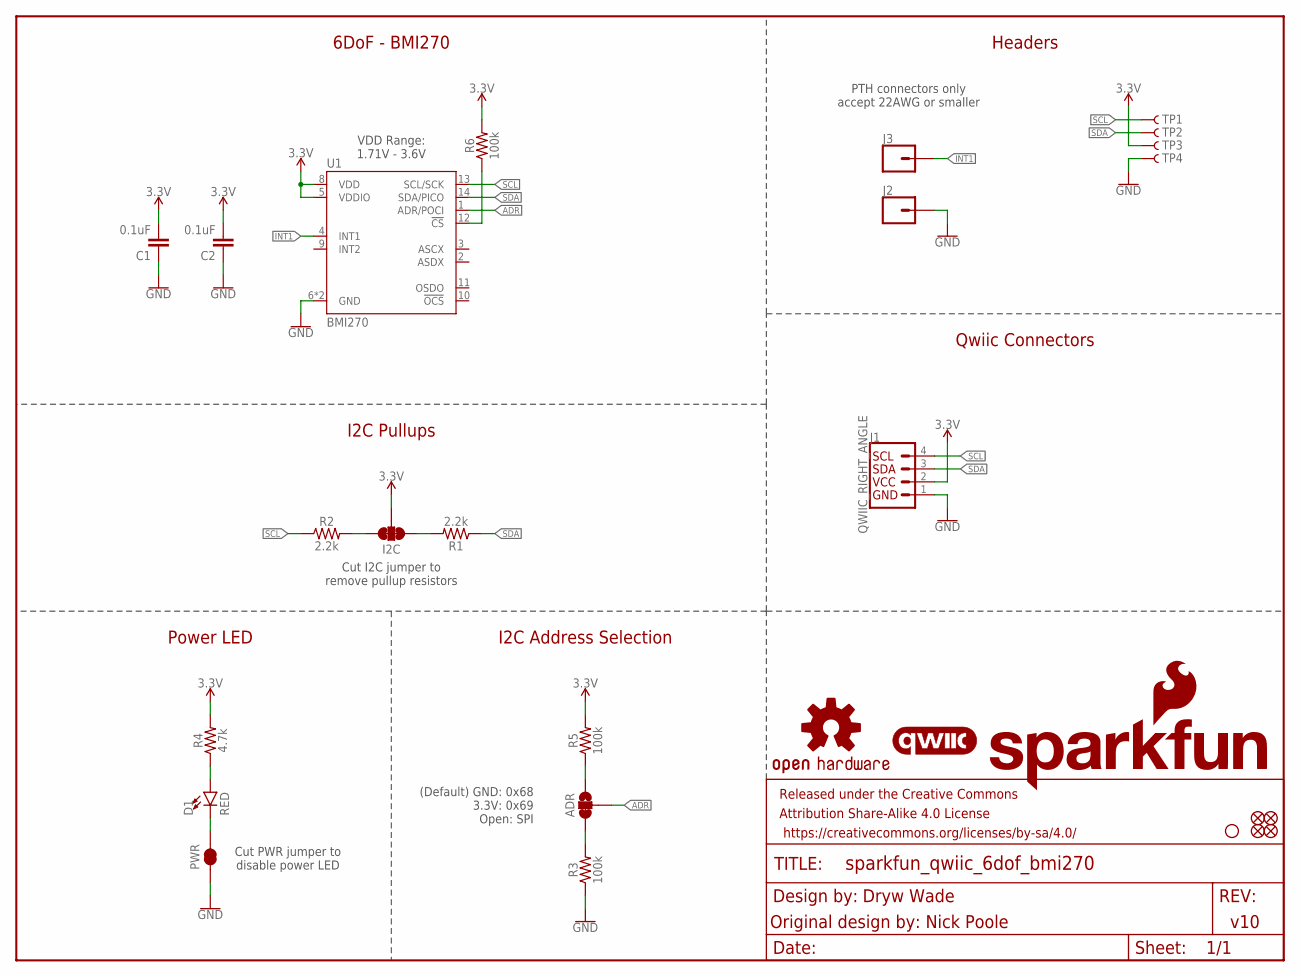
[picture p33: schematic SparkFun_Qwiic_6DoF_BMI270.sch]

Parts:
ADR: JUMPER-SMT_3_1-NC_TRACE_SILK; SMT-JUMPER_3_1-NC_TRACE_SILK
C1, C2: 0.1uF; 0402-TIGHT
D1: RED; LED-0402
FD1, FD2, FD3, FD4: FIDUCIALUFIDUCIAL; FIDUCIAL-MICRO
FRAME1: FRAME-LETTER; CREATIVE_COMMONS
H1: STAND-OFF
I2C: JUMPER-SMT_3_2-NC_TRACE_SILK; SMT-JUMPER_3_2-NC_TRACE_SILK
J1: QWIIC_RIGHT_ANGLE; JST04_1MM_RA
J2, J3: CONN_01_1MM; 1X01_1MM_NO_SILK
LOGO1: SFE_LOGO_NAME_FLAMEBLANK; BLANK
LOGO2: QWIIC_LOGO_3MM; QWIIC_3MM
LOGO3: OSHW-LOGOMINI; OSHW-LOGO-MINI
PWR: JUMPER-SMT_2_NC_TRACE_SILK; SMT-JUMPER_2_NC_TRACE_SILK
R1, R2: 2.2k; 0402-TIGHT
R3, R5, R6: 100k; 0402-TIGHT
R4: 4.7k; 0402-TIGHT
TP1, TP2, TP3, TP4: TEST-POINT3; PAD.03X.03
U1: BMI270

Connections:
3.3V: C1.2, C2.2, I2C.2, J1.2, R4.2, R5.2, R6.2, TP3.1, U1.5 (VDDIO), U1.8 (VDD)
ADR: ADR.2, U1.1 (ADR/POCI)
GND: C1.1, C2.1, J1.1, J2.1, PWR.1, R3.1, TP4.1, U1.6 (GND), U1.7 (GND)
INT1: J3.1, U1.4 (INT1)
unnamed: I2C.1, R1.2
unnamed: I2C.3, R2.2
unnamed: D1.C, PWR.2
unnamed: D1.A, R4.1
unnamed: ADR.1, R5.1
unnamed: ADR.3, R3.2
unnamed: R6.1, U1.12 (!CS!)
SCL: J1.4, R2.1, TP1.1, U1.13 (SCL/SCK)
SDA: J1.3, R1.1, TP2.1, U1.14 (SDA/PICO)

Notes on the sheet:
(Default) GND: 0x68 3.3V: 0x69 Open: SPI
Cut PWR jumper to disable power LED
Power LED
Headers
Qwiic Connectors
Dryw Wade
Original design by: Nick Poole
v10
6DoF - BMI270
Cut I2C jumper to remove pullup resistors
VDD Range: 1.71V - 3.6V
I2C Address Selection
I2C Pullups
PTH connectors only accept 22AWG or smaller

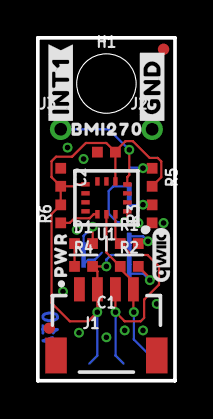
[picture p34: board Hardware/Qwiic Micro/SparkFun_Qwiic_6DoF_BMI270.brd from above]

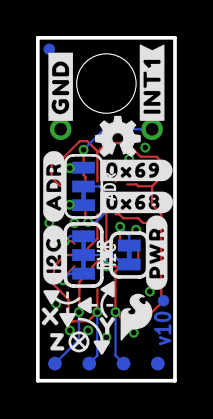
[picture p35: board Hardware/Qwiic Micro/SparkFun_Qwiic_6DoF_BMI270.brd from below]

Board: 2 copper layers, 7.6 x 19.1 mm, 45 parts (22 on the bottom side), 13 nets.

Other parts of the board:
U$1: #I2C#0
U$2, U$7: #GND#0
U$3: SFE_LOGO_FLAME_.1
U$4: #PWR#0
U$5: #ADR#0
U$6: #0X68#0
U$8, U$9: #INT1#0
U$18: #0X69#0
U$21: BMI2700
U$33: ORDERING_INSTRUCTIONS
U$34: PWR0
U$79: X0
U$80: Y0
U$81: Z0

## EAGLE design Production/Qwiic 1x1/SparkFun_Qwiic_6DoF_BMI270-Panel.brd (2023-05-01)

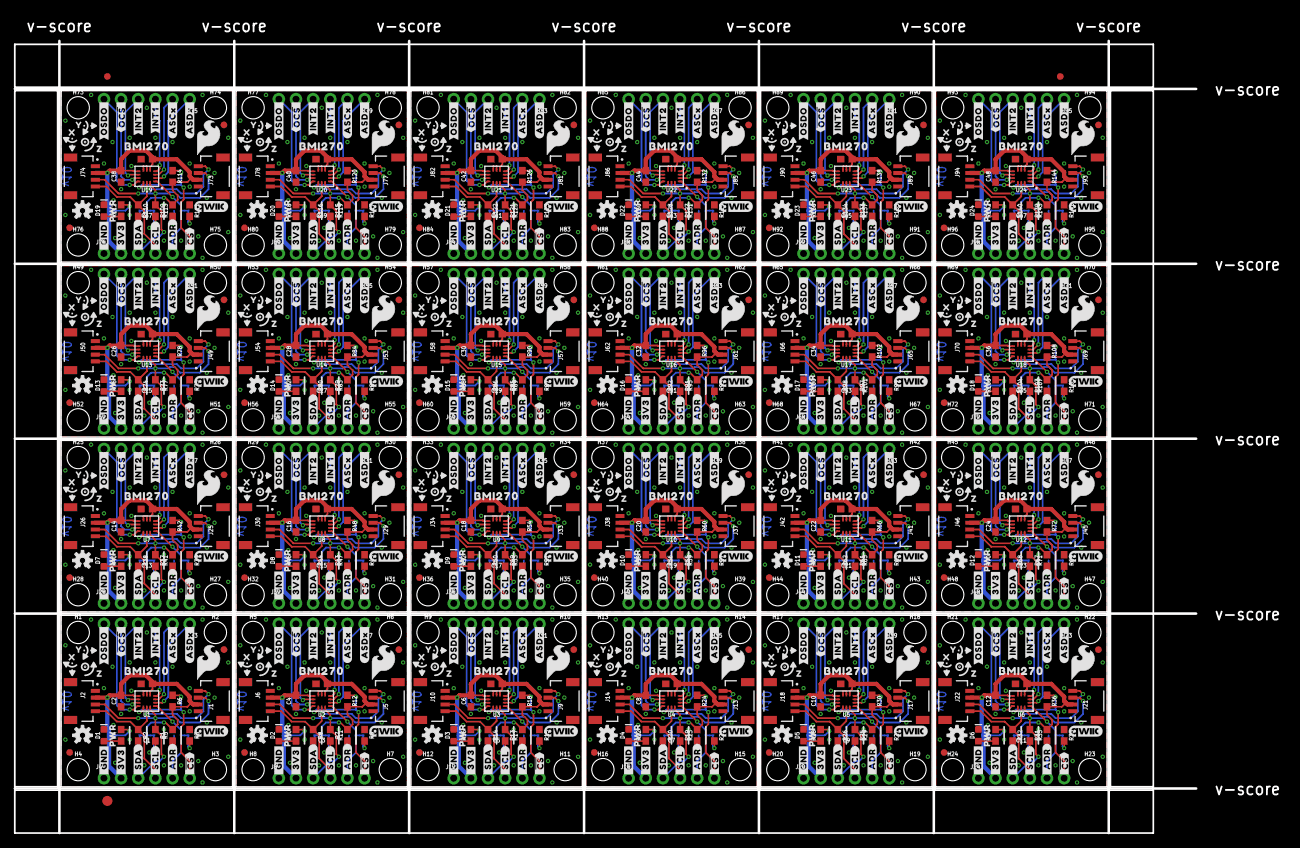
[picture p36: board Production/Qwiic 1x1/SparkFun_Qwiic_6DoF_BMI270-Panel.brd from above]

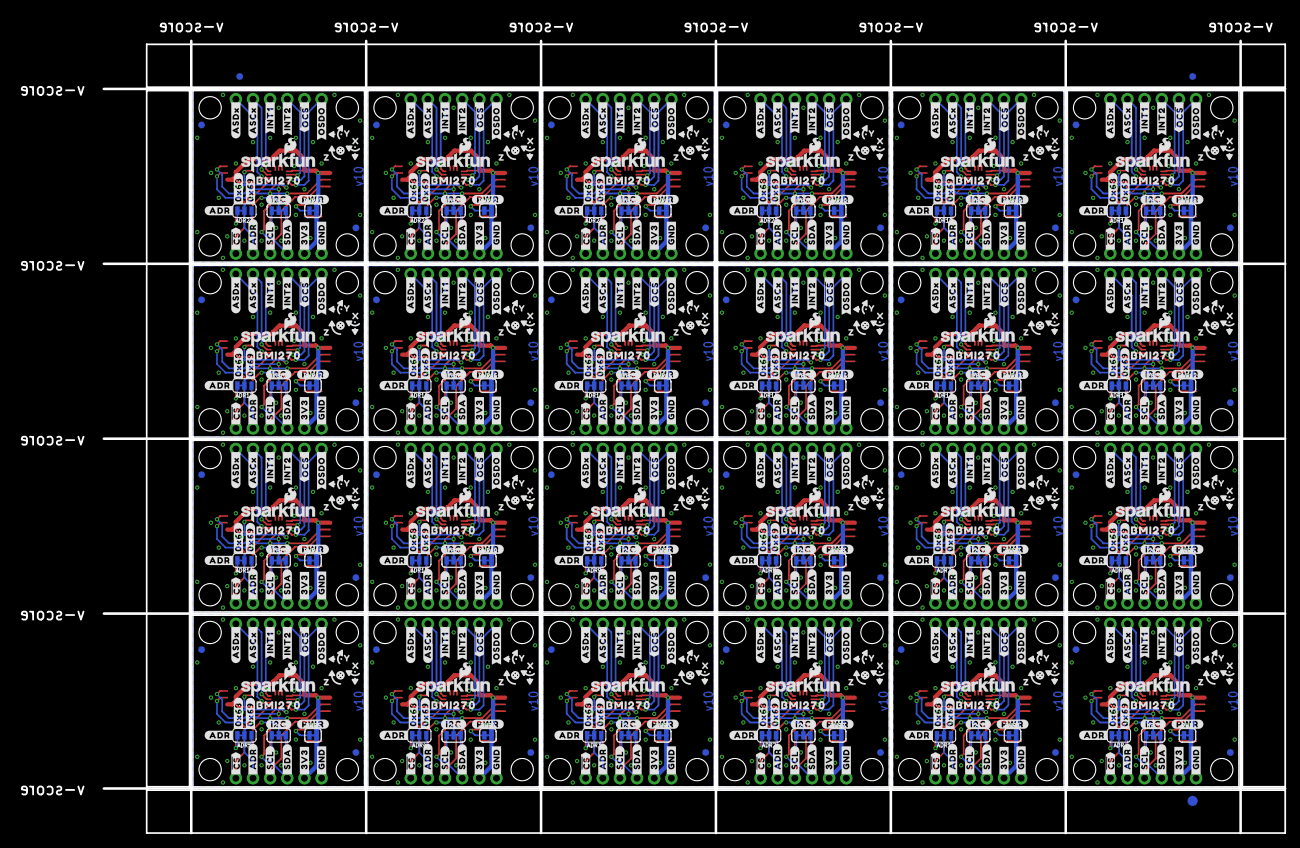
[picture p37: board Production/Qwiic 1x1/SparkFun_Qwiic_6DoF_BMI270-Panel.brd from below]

Board: 2 copper layers, 175.0 x 117.3 mm, 1614 parts (651 on the bottom side), 432 nets.

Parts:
ADR, ADR1, ADR2, ADR3, ADR4, ADR5, ADR6, ADR7, ADR8, ADR9, ADR10, ADR11, ADR12, ADR13, ADR14, ADR15, ADR16, ADR17, ADR18, ADR19, ADR20, ADR21, ADR22, ADR23: JUMPER-SMT_3_1-NC_TRACE_SILK; SMT-JUMPER_3_1-NC_TRACE_SILK
C1, C2, C3, C4, C5, C6, C7, C8, C9, C10, C11, C12, C13, C14, C15, C16, C17, C18, C19, C20, C21, C22, C23, C24, C25, C26, C27, C28, C29, C30, C31, C32, C33, C34, C35, C36, C37, C38, C39, C40, C41, C42, C43, C44, C45, C46, C47, C48: 0.1uF; 0603
D1, D2, D3, D4, D5, D6, D7, D8, D9, D10, D11, D12, D13, D14, D15, D16, D17, D18, D19, D20, D21, D22, D23, D24: RED; LED-0603
E$1, E$2, E$3, E$4: FIDUCIAL-1X2
E$5, E$6: FIDUCIAL-1.5X3
FD1, FD2, FD3, FD4, FD5, FD6, FD7, FD8, FD9, FD10, FD11, FD12, FD13, FD14, FD15, FD16, FD17, FD18, FD19, FD20, FD21, FD22, FD23, FD24, FD25, FD26, FD27, FD28, FD29, FD30, FD31, FD32, FD33, FD34, FD35, FD36, FD37, FD38, FD39, FD40, FD41, FD42, FD43, FD44, FD45, FD46, FD47, FD48, FD49, FD50, FD51, FD52, FD53, FD54, FD55, FD56, FD57, FD58, FD59, FD60, FD61, FD62, FD63, FD64, FD65, FD66, FD67, FD68, FD69, FD70, FD71, FD72, FD73, FD74, FD75, FD76, FD77, FD78, FD79, FD80, FD81, FD82, FD83, FD84, FD85, FD86, FD87, FD88, FD89, FD90, FD91, FD92, FD93, FD94, FD95, FD96: FIDUCIAL1X2; FIDUCIAL-1X2
H1, H2, H3, H4, H5, H6, H7, H8, H9, H10, H11, H12, H13, H14, H15, H16, H17, H18, H19, H20, H21, H22, H23, H24, H25, H26, H27, H28, H29, H30, H31, H32, H33, H34, H35, H36, H37, H38, H39, H40, H41, H42, H43, H44, H45, H46, H47, H48, H49, H50, H51, H52, H53, H54, H55, H56, H57, H58, H59, H60, H61, H62, H63, H64, H65, H66, H67, H68, H69, H70, H71, H72, H73, H74, H75, H76, H77, H78, H79, H80, H81, H82, H83, H84, H85, H86, H87, H88, H89, H90, H91, H92, H93, H94, H95, H96: STAND-OFF
I2C, I2C1, I2C2, I2C3, I2C4, I2C5, I2C6, I2C7, I2C8, I2C9, I2C10, I2C11, I2C12, I2C13, I2C14, I2C15, I2C16, I2C17, I2C18, I2C19, I2C20, I2C21, I2C22, I2C23: JUMPER-SMT_3_2-NC_TRACE_SILK; SMT-JUMPER_3_2-NC_TRACE_SILK
J1, J2, J5, J6, J9, J10, J13, J14, J17, J18, J21, J22, J25, J26, J29, J30, J33, J34, J37, J38, J41, J42, J45, J46, J49, J50, J53, J54, J57, J58, J61, J62, J65, J66, J69, J70, J73, J74, J77, J78, J81, J82, J85, J86, J89, J90, J93, J94: QWIIC_RIGHT_ANGLE; JST04_1MM_RA
J3, J4, J7, J8, J11, J12, J15, J16, J19, J20, J23, J24, J27, J28, J31, J32, J35, J36, J39, J40, J43, J44, J47, J48, J51, J52, J55, J56, J59, J60, J63, J64, J67, J68, J71, J72, J75, J76, J79, J80, J83, J84, J87, J88, J91, J92, J95, J96: 1X06_NO_SILK
LOGO1, LOGO4, LOGO7, LOGO10, LOGO13, LOGO16, LOGO19, LOGO22, LOGO25, LOGO28, LOGO31, LOGO34, LOGO37, LOGO40, LOGO43, LOGO46, LOGO49, LOGO52, LOGO55, LOGO58, LOGO61, LOGO64, LOGO67, LOGO70: SFE_LOGO_NAME_FLAME.1_INCH; SFE_LOGO_NAME_FLAME_.1
LOGO2, LOGO5, LOGO8, LOGO11, LOGO14, LOGO17, LOGO20, LOGO23, LOGO26, LOGO29, LOGO32, LOGO35, LOGO38, LOGO41, LOGO44, LOGO47, LOGO50, LOGO53, LOGO56, LOGO59, LOGO62, LOGO65, LOGO68, LOGO71: QWIIC_LOGO_5MM; QWIIC_5MM
LOGO3, LOGO6, LOGO9, LOGO12, LOGO15, LOGO18, LOGO21, LOGO24, LOGO27, LOGO30, LOGO33, LOGO36, LOGO39, LOGO42, LOGO45, LOGO48, LOGO51, LOGO54, LOGO57, LOGO60, LOGO63, LOGO66, LOGO69, LOGO72: OSHW-LOGOS; OSHW-LOGO-S
PWR, PWR1, PWR2, PWR3, PWR4, PWR5, PWR6, PWR7, PWR8, PWR9, PWR10, PWR11, PWR12, PWR13, PWR14, PWR15, PWR16, PWR17, PWR18, PWR19, PWR20, PWR21, PWR22, PWR23: JUMPER-SMT_2_NC_TRACE_SILK; SMT-JUMPER_2_NC_TRACE_SILK
R1, R2, R7, R8, R13, R14, R19, R20, R25, R26, R31, R32, R37, R38, R43, R44, R49, R50, R55, R56, R61, R62, R67, R68, R73, R74, R79, R80, R85, R86, R91, R92, R97, R98, R103, R104, R109, R110, R115, R116, R121, R122, R127, R128, R133, R134, R139, R140: 2.2k; 0603
R3, R5, R6, R9, R11, R12, R15, R17, R18, R21, R23, R24, R27, R29, R30, R33, R35, R36, R39, R41, R42, R45, R47, R48, R51, R53, R54, R57, R59, R60, R63, R65, R66, R69, R71, R72, R75, R77, R78, R81, R83, R84, R87, R89, R90, R93, R95, R96, R99, R101, R102, R105, R107, R108, R111, R113, R114, R117, R119, R120, R123, R125, R126, R129, R131, R132, R135, R137, R138, R141, R143, R144: 100k; 0603
R4, R10, R16, R22, R28, R34, R40, R46, R52, R58, R64, R70, R76, R82, R88, R94, R100, R106, R112, R118, R124, R130, R136, R142: 4.7k; 0603
U1, U2, U3, U4, U5, U6, U7, U8, U9, U10, U11, U12, U13, U14, U15, U16, U17, U18, U19, U20, U21, U22, U23, U24: BMI270
U$1, U$38, U$77, U$122, U$161, U$200, U$239, U$278, U$317, U$356, U$395, U$434, U$473, U$512, U$551, U$590, U$629, U$668, U$707, U$746, U$785, U$824, U$863, U$902: #I2C#0
U$2, U$14, U$47, U$59, U$92, U$104, U$131, U$143, U$170, U$182, U$209, U$221, U$248, U$260, U$287, U$299, U$326, U$338, U$365, U$377, U$404, U$416, U$443, U$455, U$482, U$494, U$521, U$533, U$560, U$572, U$599, U$611, U$638, U$650, U$677, U$689, U$716, U$728, U$755, U$767, U$794, U$806, U$833, U$845, U$872, U$884, U$911, U$923: #_SDA#0
U$3, U$37, U$76, U$121, U$160, U$199, U$238, U$277, U$316, U$355, U$394, U$433, U$472, U$511, U$550, U$589, U$628, U$667, U$706, U$745, U$784, U$823, U$862, U$901: SFE_LOGO_FLAME_.2
U$4, U$39, U$78, U$123, U$162, U$201, U$240, U$279, U$318, U$357, U$396, U$435, U$474, U$513, U$552, U$591, U$630, U$669, U$708, U$747, U$786, U$825, U$864, U$903: #PWR#0
U$5, U$40, U$82, U$124, U$163, U$202, U$241, U$280, U$319, U$358, U$397, U$436, U$475, U$514, U$553, U$592, U$631, U$670, U$709, U$748, U$787, U$826, U$865, U$904: #ADR#0
U$6, U$41, U$83, U$125, U$164, U$203, U$242, U$281, U$320, U$359, U$398, U$437, U$476, U$515, U$554, U$593, U$632, U$671, U$710, U$749, U$788, U$827, U$866, U$905: #0X68#0
U$7, U$13, U$46, U$58, U$91, U$103, U$130, U$142, U$169, U$181, U$208, U$220, U$247, U$259, U$286, U$298, U$325, U$337, U$364, U$376, U$403, U$415, U$442, U$454, U$481, U$493, U$520, U$532, U$559, U$571, U$598, U$610, U$637, U$649, U$676, U$688, U$715, U$727, U$754, U$766, U$793, U$805, U$832, U$844, U$871, U$883, U$910, U$922: #_3V3#0
U$8, U$17, U$50, U$62, U$95, U$107, U$134, U$146, U$173, U$185, U$212, U$224, U$251, U$263, U$290, U$302, U$329, U$341, U$368, U$380, U$407, U$419, U$446, U$458, U$485, U$497, U$524, U$536, U$563, U$575, U$602, U$614, U$641, U$653, U$680, U$692, U$719, U$731, U$758, U$770, U$797, U$809, U$836, U$848, U$875, U$887, U$914, U$926: #_#CS##0
U$9, U$16, U$49, U$61, U$94, U$106, U$133, U$145, U$172, U$184, U$211, U$223, U$250, U$262, U$289, U$301, U$328, U$340, U$367, U$379, U$406, U$418, U$445, U$457, U$484, U$496, U$523, U$535, U$562, U$574, U$601, U$613, U$640, U$652, U$679, U$691, U$718, U$730, U$757, U$769, U$796, U$808, U$835, U$847, U$874, U$886, U$913, U$925: #_ADR#0
U$10, U$15, U$48, U$60, U$93, U$105, U$132, U$144, U$171, U$183, U$210, U$222, U$249, U$261, U$288, U$300, U$327, U$339, U$366, U$378, U$405, U$417, U$444, U$456, U$483, U$495, U$522, U$534, U$561, U$573, U$600, U$612, U$639, U$651, U$678, U$690, U$717, U$729, U$756, U$768, U$795, U$807, U$834, U$846, U$873, U$885, U$912, U$924: #_SCL#0
U$11, U$27, U$51, U$63, U$96, U$108, U$135, U$147, U$174, U$186, U$213, U$225, U$252, U$264, U$291, U$303, U$330, U$342, U$369, U$381, U$408, U$420, U$447, U$459, U$486, U$498, U$525, U$537, U$564, U$576, U$603, U$615, U$642, U$654, U$681, U$693, U$720, U$732, U$759, U$771, U$798, U$810, U$837, U$849, U$876, U$888, U$915, U$927: #ASDX_#0
U$12, U$19, U$45, U$57, U$87, U$102, U$129, U$141, U$168, U$180, U$207, U$219, U$246, U$258, U$285, U$297, U$324, U$336, U$363, U$375, U$402, U$414, U$441, U$453, U$480, U$492, U$519, U$531, U$558, U$570, U$597, U$609, U$636, U$648, U$675, U$687, U$714, U$726, U$753, U$765, U$792, U$804, U$831, U$843, U$870, U$882, U$909, U$921: #_GND#0
U$18, U$42, U$84, U$126, U$165, U$204, U$243, U$282, U$321, U$360, U$399, U$438, U$477, U$516, U$555, U$594, U$633, U$672, U$711, U$750, U$789, U$828, U$867, U$906: #0X69#0
U$20, U$21, U$43, U$44, U$85, U$86, U$127, U$128, U$166, U$167, U$205, U$206, U$244, U$245, U$283, U$284, U$322, U$323, U$361, U$362, U$400, U$401, U$439, U$440, U$478, U$479, U$517, U$518, U$556, U$557, U$595, U$596, U$634, U$635, U$673, U$674, U$712, U$713, U$751, U$752, U$790, U$791, U$829, U$830, U$868, U$869, U$907, U$908: BMI2700
U$22, U$28, U$52, U$64, U$97, U$109, U$136, U$148, U$175, U$187, U$214, U$226, U$253, U$265, U$292, U$304, U$331, U$343, U$370, U$382, U$409, U$421, U$448, U$460, U$487, U$499, U$526, U$538, U$565, U$577, U$604, U$616, U$643, U$655, U$682, U$694, U$721, U$733, U$760, U$772, U$799, U$811, U$838, U$850, U$877, U$889, U$916, U$928: #ASCX_#0
U$23, U$29, U$53, U$65, U$98, U$110, U$137, U$149, U$176, U$188, U$215, U$227, U$254, U$266, U$293, U$305, U$332, U$344, U$371, U$383, U$410, U$422, U$449, U$461, U$488, U$500, U$527, U$539, U$566, U$578, U$605, U$617, U$644, U$656, U$683, U$695, U$722, U$734, U$761, U$773, U$800, U$812, U$839, U$851, U$878, U$890, U$917, U$929: #INT1_#0
U$24, U$30, U$54, U$66, U$99, U$111, U$138, U$150, U$177, U$189, U$216, U$228, U$255, U$267, U$294, U$306, U$333, U$345, U$372, U$384, U$411, U$423, U$450, U$462, U$489, U$501, U$528, U$540, U$567, U$579, U$606, U$618, U$645, U$657, U$684, U$696, U$723, U$735, U$762, U$774, U$801, U$813, U$840, U$852, U$879, U$891, U$918, U$930: #INT2_#0
U$25, U$31, U$55, U$67, U$100, U$112, U$139, U$151, U$178, U$190, U$217, U$229, U$256, U$268, U$295, U$307, U$334, U$346, U$373, U$385, U$412, U$424, U$451, U$463, U$490, U$502, U$529, U$541, U$568, U$580, U$607, U$619, U$646, U$658, U$685, U$697, U$724, U$736, U$763, U$775, U$802, U$814, U$841, U$853, U$880, U$892, U$919, U$931: ##OCS#_#0
U$26, U$32, U$56, U$68, U$101, U$113, U$140, U$152, U$179, U$191, U$218, U$230, U$257, U$269, U$296, U$308, U$335, U$347, U$374, U$386, U$413, U$425, U$452, U$464, U$491, U$503, U$530, U$542, U$569, U$581, U$608, U$620, U$647, U$659, U$686, U$698, U$725, U$737, U$764, U$776, U$803, U$815, U$842, U$854, U$881, U$893, U$920, U$932: #OSDO_#0
U$33, U$69, U$73, U$79, U$88, U$114, U$118, U$153, U$157, U$192, U$196, U$231, U$235, U$270, U$274, U$309, U$313, U$348, U$352, U$387, U$391, U$426, U$430, U$465, U$469, U$504, U$508, U$543, U$547, U$582, U$586, U$621, U$625, U$660, U$664, U$699, U$703, U$738, U$742, U$777, U$781, U$816, U$820, U$855, U$859, U$894, U$898, U$933: X0
U$34, U$72, U$117, U$156, U$195, U$234, U$273, U$312, U$351, U$390, U$429, U$468, U$507, U$546, U$585, U$624, U$663, U$702, U$741, U$780, U$819, U$858, U$897, U$936: PWR0
U$35, U$70, U$74, U$80, U$89, U$115, U$119, U$154, U$158, U$193, U$197, U$232, U$236, U$271, U$275, U$310, U$314, U$349, U$353, U$388, U$392, U$427, U$431, U$466, U$470, U$505, U$509, U$544, U$548, U$583, U$587, U$622, U$626, U$661, U$665, U$700, U$704, U$739, U$743, U$778, U$782, U$817, U$821, U$856, U$860, U$895, U$899, U$934: Y0
U$36, U$71, U$75, U$81, U$90, U$116, U$120, U$155, U$159, U$194, U$198, U$233, U$237, U$272, U$276, U$311, U$315, U$350, U$354, U$389, U$393, U$428, U$432, U$467, U$471, U$506, U$510, U$545, U$549, U$584, U$588, U$623, U$627, U$662, U$666, U$701, U$705, U$740, U$744, U$779, U$783, U$818, U$822, U$857, U$861, U$896, U$900, U$935: Z0

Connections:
3.3V: C1.2, C2.2, I2C.2, J1.2, J2.2, J4.2, PWR.2, R5.2, R6.2, U1.5, U1.8
3.3V1: C3.2, C4.2, I2C1.2, J5.2, J6.2, J8.2, PWR1.2, R11.2, R12.2, U2.5, U2.8
3.3V2: C5.2, C6.2, I2C2.2, J9.2, J10.2, J12.2, PWR2.2, R17.2, R18.2, U3.5, U3.8
3.3V3: C7.2, C8.2, I2C3.2, J13.2, J14.2, J16.2, PWR3.2, R23.2, R24.2, U4.5, U4.8
3.3V4: C9.2, C10.2, I2C4.2, J17.2, J18.2, J20.2, PWR4.2, R29.2, R30.2, U5.5, U5.8
3.3V5: C11.2, C12.2, I2C5.2, J21.2, J22.2, J24.2, PWR5.2, R35.2, R36.2, U6.5, U6.8
3.3V6: C13.2, C14.2, I2C6.2, J25.2, J26.2, J28.2, PWR6.2, R41.2, R42.2, U7.5, U7.8
3.3V7: C15.2, C16.2, I2C7.2, J29.2, J30.2, J32.2, PWR7.2, R47.2, R48.2, U8.5, U8.8
3.3V8: C17.2, C18.2, I2C8.2, J33.2, J34.2, J36.2, PWR8.2, R53.2, R54.2, U9.5, U9.8
3.3V9: C19.2, C20.2, I2C9.2, J37.2, J38.2, J40.2, PWR9.2, R59.2, R60.2, U10.5, U10.8
3.3V10: C21.2, C22.2, I2C10.2, J41.2, J42.2, J44.2, PWR10.2, R65.2, R66.2, U11.5, U11.8
3.3V11: C23.2, C24.2, I2C11.2, J45.2, J46.2, J48.2, PWR11.2, R71.2, R72.2, U12.5, U12.8
3.3V12: C25.2, C26.2, I2C12.2, J49.2, J50.2, J52.2, PWR12.2, R77.2, R78.2, U13.5, U13.8
3.3V13: C27.2, C28.2, I2C13.2, J53.2, J54.2, J56.2, PWR13.2, R83.2, R84.2, U14.5, U14.8
3.3V14: C29.2, C30.2, I2C14.2, J57.2, J58.2, J60.2, PWR14.2, R89.2, R90.2, U15.5, U15.8
3.3V15: C31.2, C32.2, I2C15.2, J61.2, J62.2, J64.2, PWR15.2, R95.2, R96.2, U16.5, U16.8
3.3V16: C33.2, C34.2, I2C16.2, J65.2, J66.2, J68.2, PWR16.2, R101.2, R102.2, U17.5, U17.8
3.3V17: C35.2, C36.2, I2C17.2, J69.2, J70.2, J72.2, PWR17.2, R107.2, R108.2, U18.5, U18.8
3.3V18: C37.2, C38.2, I2C18.2, J73.2, J74.2, J76.2, PWR18.2, R113.2, R114.2, U19.5, U19.8
3.3V19: C39.2, C40.2, I2C19.2, J77.2, J78.2, J80.2, PWR19.2, R119.2, R120.2, U20.5, U20.8
3.3V20: C41.2, C42.2, I2C20.2, J81.2, J82.2, J84.2, PWR20.2, R125.2, R126.2, U21.5, U21.8
3.3V21: C43.2, C44.2, I2C21.2, J85.2, J86.2, J88.2, PWR21.2, R131.2, R132.2, U22.5, U22.8
3.3V22: C45.2, C46.2, I2C22.2, J89.2, J90.2, J92.2, PWR22.2, R137.2, R138.2, U23.5, U23.8
3.3V23: C47.2, C48.2, I2C23.2, J93.2, J94.2, J96.2, PWR23.2, R143.2, R144.2, U24.5, U24.8
!CS!: J4.6, R6.1, U1.12
!CS!1: J8.6, R12.1, U2.12
!CS!2: J12.6, R18.1, U3.12
!CS!3: J16.6, R24.1, U4.12
!CS!4: J20.6, R30.1, U5.12
!CS!5: J24.6, R36.1, U6.12
!CS!6: J28.6, R42.1, U7.12
!CS!7: J32.6, R48.1, U8.12
!CS!8: J36.6, R54.1, U9.12
!CS!9: J40.6, R60.1, U10.12
!CS!10: J44.6, R66.1, U11.12
!CS!11: J48.6, R72.1, U12.12
!CS!12: J52.6, R78.1, U13.12
!CS!13: J56.6, R84.1, U14.12
!CS!14: J60.6, R90.1, U15.12
!CS!15: J64.6, R96.1, U16.12
!CS!16: J68.6, R102.1, U17.12
!CS!17: J72.6, R108.1, U18.12
!CS!18: J76.6, R114.1, U19.12
!CS!19: J80.6, R120.1, U20.12
!CS!20: J84.6, R126.1, U21.12
!CS!21: J88.6, R132.1, U22.12
!CS!22: J92.6, R138.1, U23.12
!CS!23: J96.6, R144.1, U24.12
!OCS!: J3.5, U1.10
!OCS!1: J7.5, U2.10
!OCS!2: J11.5, U3.10
!OCS!3: J15.5, U4.10
!OCS!4: J19.5, U5.10
!OCS!5: J23.5, U6.10
!OCS!6: J27.5, U7.10
!OCS!7: J31.5, U8.10
!OCS!8: J35.5, U9.10
!OCS!9: J39.5, U10.10
!OCS!10: J43.5, U11.10
!OCS!11: J47.5, U12.10
!OCS!12: J51.5, U13.10
!OCS!13: J55.5, U14.10
!OCS!14: J59.5, U15.10
!OCS!15: J63.5, U16.10
!OCS!16: J67.5, U17.10
!OCS!17: J71.5, U18.10
!OCS!18: J75.5, U19.10
!OCS!19: J79.5, U20.10
!OCS!20: J83.5, U21.10
!OCS!21: J87.5, U22.10
!OCS!22: J91.5, U23.10
!OCS!23: J95.5, U24.10
ADR/POCI: ADR.2, J4.5, U1.1
ADR/POCI1: ADR1.2, J8.5, U2.1
ADR/POCI2: ADR2.2, J12.5, U3.1
ADR/POCI3: ADR3.2, J16.5, U4.1
ADR/POCI4: ADR4.2, J20.5, U5.1
ADR/POCI5: ADR5.2, J24.5, U6.1
ADR/POCI6: ADR6.2, J28.5, U7.1
ADR/POCI7: ADR7.2, J32.5, U8.1
ADR/POCI8: ADR8.2, J36.5, U9.1
ADR/POCI9: ADR9.2, J40.5, U10.1
ADR/POCI10: ADR10.2, J44.5, U11.1
ADR/POCI11: ADR11.2, J48.5, U12.1
ADR/POCI12: ADR12.2, J52.5, U13.1
ADR/POCI13: ADR13.2, J56.5, U14.1
ADR/POCI14: ADR14.2, J60.5, U15.1
ADR/POCI15: ADR15.2, J64.5, U16.1
ADR/POCI16: ADR16.2, J68.5, U17.1
ADR/POCI17: ADR17.2, J72.5, U18.1
ADR/POCI18: ADR18.2, J76.5, U19.1
ADR/POCI19: ADR19.2, J80.5, U20.1
ADR/POCI20: ADR20.2, J84.5, U21.1
ADR/POCI21: ADR21.2, J88.5, U22.1
ADR/POCI22: ADR22.2, J92.5, U23.1
ADR/POCI23: ADR23.2, J96.5, U24.1
ASCX: J3.2, U1.3
ASCX1: J7.2, U2.3
ASCX2: J11.2, U3.3
ASCX3: J15.2, U4.3
ASCX4: J19.2, U5.3
ASCX5: J23.2, U6.3
ASCX6: J27.2, U7.3
ASCX7: J31.2, U8.3
ASCX8: J35.2, U9.3
ASCX9: J39.2, U10.3
ASCX10: J43.2, U11.3
ASCX11: J47.2, U12.3
ASCX12: J51.2, U13.3
ASCX13: J55.2, U14.3
ASCX14: J59.2, U15.3
ASCX15: J63.2, U16.3
ASCX16: J67.2, U17.3
ASCX17: J71.2, U18.3
ASCX18: J75.2, U19.3
ASCX19: J79.2, U20.3
ASCX20: J83.2, U21.3
ASCX21: J87.2, U22.3
ASCX22: J91.2, U23.3
ASCX23: J95.2, U24.3
ASDX: J3.1, U1.2
ASDX1: J7.1, U2.2
ASDX2: J11.1, U3.2
ASDX3: J15.1, U4.2
ASDX4: J19.1, U5.2
ASDX5: J23.1, U6.2
ASDX6: J27.1, U7.2
ASDX7: J31.1, U8.2
ASDX8: J35.1, U9.2
ASDX9: J39.1, U10.2
ASDX10: J43.1, U11.2
ASDX11: J47.1, U12.2
ASDX12: J51.1, U13.2
ASDX13: J55.1, U14.2
ASDX14: J59.1, U15.2
ASDX15: J63.1, U16.2
ASDX16: J67.1, U17.2
ASDX17: J71.1, U18.2
ASDX18: J75.1, U19.2
ASDX19: J79.1, U20.2
ASDX20: J83.1, U21.2
ASDX21: J87.1, U22.2
ASDX22: J91.1, U23.2
ASDX23: J95.1, U24.2
GND: C1.1, C2.1, D1.C, J1.1, J2.1, J4.1, R3.1, U1.6, U1.7
GND1: C3.1, C4.1, D2.C, J5.1, J6.1, J8.1, R9.1, U2.6, U2.7
GND2: C5.1, C6.1, D3.C, J9.1, J10.1, J12.1, R15.1, U3.6, U3.7
GND3: C7.1, C8.1, D4.C, J13.1, J14.1, J16.1, R21.1, U4.6, U4.7
GND4: C9.1, C10.1, D5.C, J17.1, J18.1, J20.1, R27.1, U5.6, U5.7
GND5: C11.1, C12.1, D6.C, J21.1, J22.1, J24.1, R33.1, U6.6, U6.7
GND6: C13.1, C14.1, D7.C, J25.1, J26.1, J28.1, R39.1, U7.6, U7.7
GND7: C15.1, C16.1, D8.C, J29.1, J30.1, J32.1, R45.1, U8.6, U8.7
GND8: C17.1, C18.1, D9.C, J33.1, J34.1, J36.1, R51.1, U9.6, U9.7
GND9: C19.1, C20.1, D10.C, J37.1, J38.1, J40.1, R57.1, U10.6, U10.7
GND10: C21.1, C22.1, D11.C, J41.1, J42.1, J44.1, R63.1, U11.6, U11.7
GND11: C23.1, C24.1, D12.C, J45.1, J46.1, J48.1, R69.1, U12.6, U12.7
GND12: C25.1, C26.1, D13.C, J49.1, J50.1, J52.1, R75.1, U13.6, U13.7
GND13: C27.1, C28.1, D14.C, J53.1, J54.1, J56.1, R81.1, U14.6, U14.7
GND14: C29.1, C30.1, D15.C, J57.1, J58.1, J60.1, R87.1, U15.6, U15.7
GND15: C31.1, C32.1, D16.C, J61.1, J62.1, J64.1, R93.1, U16.6, U16.7
GND16: C33.1, C34.1, D17.C, J65.1, J66.1, J68.1, R99.1, U17.6, U17.7
GND17: C35.1, C36.1, D18.C, J69.1, J70.1, J72.1, R105.1, U18.6, U18.7
GND18: C37.1, C38.1, D19.C, J73.1, J74.1, J76.1, R111.1, U19.6, U19.7
GND19: C39.1, C40.1, D20.C, J77.1, J78.1, J80.1, R117.1, U20.6, U20.7
GND20: C41.1, C42.1, D21.C, J81.1, J82.1, J84.1, R123.1, U21.6, U21.7
GND21: C43.1, C44.1, D22.C, J85.1, J86.1, J88.1, R129.1, U22.6, U22.7
GND22: C45.1, C46.1, D23.C, J89.1, J90.1, J92.1, R135.1, U23.6, U23.7
GND23: C47.1, C48.1, D24.C, J93.1, J94.1, J96.1, R141.1, U24.6, U24.7
INT1: J3.3, U1.4
INT2: J3.4, U1.9
INT3: J7.3, U2.4
INT4: J7.4, U2.9
INT5: J11.3, U3.4
INT6: J11.4, U3.9
INT7: J15.3, U4.4
INT8: J15.4, U4.9
INT9: J19.3, U5.4
INT10: J19.4, U5.9
INT11: J23.3, U6.4
INT12: J23.4, U6.9
INT13: J27.3, U7.4
INT14: J27.4, U7.9
INT15: J31.3, U8.4
INT16: J31.4, U8.9
INT17: J35.3, U9.4
INT18: J35.4, U9.9
INT19: J39.3, U10.4
INT20: J39.4, U10.9
INT21: J43.3, U11.4
INT22: J43.4, U11.9
INT23: J47.3, U12.4
INT24: J47.4, U12.9
INT25: J51.3, U13.4
INT26: J51.4, U13.9
INT27: J55.3, U14.4
INT28: J55.4, U14.9
INT29: J59.3, U15.4
INT30: J59.4, U15.9
INT31: J63.3, U16.4
INT32: J63.4, U16.9
INT33: J67.3, U17.4
INT34: J67.4, U17.9
INT35: J71.3, U18.4
INT36: J71.4, U18.9
INT37: J75.3, U19.4
INT38: J75.4, U19.9
INT39: J79.3, U20.4
INT40: J79.4, U20.9
INT41: J83.3, U21.4
INT42: J83.4, U21.9
INT43: J87.3, U22.4
INT44: J87.4, U22.9
INT45: J91.3, U23.4
INT46: J91.4, U23.9
INT47: J95.3, U24.4
INT48: J95.4, U24.9
unnamed: I2C.1, R1.2
unnamed: I2C.3, R2.2
unnamed: PWR.1, R4.2
unnamed: D1.A, R4.1
unnamed: ADR.1, R5.1
unnamed: ADR.3, R3.2
unnamed: I2C1.1, R7.2
unnamed: I2C1.3, R8.2
unnamed: PWR1.1, R10.2
unnamed: D2.A, R10.1
unnamed: ADR1.1, R11.1
unnamed: ADR1.3, R9.2
unnamed: I2C2.1, R13.2
unnamed: I2C2.3, R14.2
unnamed: PWR2.1, R16.2
unnamed: D3.A, R16.1
unnamed: ADR2.1, R17.1
unnamed: ADR2.3, R15.2
unnamed: I2C3.1, R19.2
unnamed: I2C3.3, R20.2
unnamed: PWR3.1, R22.2
unnamed: D4.A, R22.1
unnamed: ADR3.1, R23.1
unnamed: ADR3.3, R21.2
unnamed: I2C4.1, R25.2
unnamed: I2C4.3, R26.2
unnamed: PWR4.1, R28.2
unnamed: D5.A, R28.1
unnamed: ADR4.1, R29.1
unnamed: ADR4.3, R27.2
unnamed: I2C5.1, R31.2
unnamed: I2C5.3, R32.2
unnamed: PWR5.1, R34.2
unnamed: D6.A, R34.1
unnamed: ADR5.1, R35.1
unnamed: ADR5.3, R33.2
unnamed: I2C6.1, R37.2
unnamed: I2C6.3, R38.2
unnamed: PWR6.1, R40.2
unnamed: D7.A, R40.1
unnamed: ADR6.1, R41.1
unnamed: ADR6.3, R39.2
unnamed: I2C7.1, R43.2
unnamed: I2C7.3, R44.2
unnamed: PWR7.1, R46.2
unnamed: D8.A, R46.1
unnamed: ADR7.1, R47.1
unnamed: ADR7.3, R45.2
unnamed: I2C8.1, R49.2
unnamed: I2C8.3, R50.2
unnamed: PWR8.1, R52.2
unnamed: D9.A, R52.1
unnamed: ADR8.1, R53.1
unnamed: ADR8.3, R51.2
unnamed: I2C9.1, R55.2
unnamed: I2C9.3, R56.2
unnamed: PWR9.1, R58.2
unnamed: D10.A, R58.1
unnamed: ADR9.1, R59.1
unnamed: ADR9.3, R57.2
unnamed: I2C10.1, R61.2
unnamed: I2C10.3, R62.2
unnamed: PWR10.1, R64.2
unnamed: D11.A, R64.1
unnamed: ADR10.1, R65.1
unnamed: ADR10.3, R63.2
unnamed: I2C11.1, R67.2
unnamed: I2C11.3, R68.2
unnamed: PWR11.1, R70.2
unnamed: D12.A, R70.1
unnamed: ADR11.1, R71.1
unnamed: ADR11.3, R69.2
unnamed: I2C12.1, R73.2
unnamed: I2C12.3, R74.2
unnamed: PWR12.1, R76.2
unnamed: D13.A, R76.1
unnamed: ADR12.1, R77.1
unnamed: ADR12.3, R75.2
unnamed: I2C13.1, R79.2
unnamed: I2C13.3, R80.2
unnamed: PWR13.1, R82.2
unnamed: D14.A, R82.1
unnamed: ADR13.1, R83.1
unnamed: ADR13.3, R81.2
unnamed: I2C14.1, R85.2
unnamed: I2C14.3, R86.2
unnamed: PWR14.1, R88.2
unnamed: D15.A, R88.1
unnamed: ADR14.1, R89.1
unnamed: ADR14.3, R87.2
unnamed: I2C15.1, R91.2
unnamed: I2C15.3, R92.2
unnamed: PWR15.1, R94.2
unnamed: D16.A, R94.1
unnamed: ADR15.1, R95.1
unnamed: ADR15.3, R93.2
unnamed: I2C16.1, R97.2
unnamed: I2C16.3, R98.2
unnamed: PWR16.1, R100.2
unnamed: D17.A, R100.1
unnamed: ADR16.1, R101.1
unnamed: ADR16.3, R99.2
unnamed: I2C17.1, R103.2
unnamed: I2C17.3, R104.2
unnamed: PWR17.1, R106.2
unnamed: D18.A, R106.1
unnamed: ADR17.1, R107.1
unnamed: ADR17.3, R105.2
unnamed: I2C18.1, R109.2
unnamed: I2C18.3, R110.2
unnamed: PWR18.1, R112.2
unnamed: D19.A, R112.1
unnamed: ADR18.1, R113.1
unnamed: ADR18.3, R111.2
unnamed: I2C19.1, R115.2
unnamed: I2C19.3, R116.2
unnamed: PWR19.1, R118.2
unnamed: D20.A, R118.1
unnamed: ADR19.1, R119.1
unnamed: ADR19.3, R117.2
unnamed: I2C20.1, R121.2
unnamed: I2C20.3, R122.2
unnamed: PWR20.1, R124.2
unnamed: D21.A, R124.1
unnamed: ADR20.1, R125.1
unnamed: ADR20.3, R123.2
unnamed: I2C21.1, R127.2
unnamed: I2C21.3, R128.2
unnamed: PWR21.1, R130.2
unnamed: D22.A, R130.1
unnamed: ADR21.1, R131.1
unnamed: ADR21.3, R129.2
unnamed: I2C22.1, R133.2
unnamed: I2C22.3, R134.2
unnamed: PWR22.1, R136.2
unnamed: D23.A, R136.1
unnamed: ADR22.1, R137.1
unnamed: ADR22.3, R135.2
unnamed: I2C23.1, R139.2
unnamed: I2C23.3, R140.2
unnamed: PWR23.1, R142.2
unnamed: D24.A, R142.1
unnamed: ADR23.1, R143.1
unnamed: ADR23.3, R141.2
OSDO: J3.6, U1.11
OSDO1: J7.6, U2.11
OSDO2: J11.6, U3.11
OSDO3: J15.6, U4.11
OSDO4: J19.6, U5.11
OSDO5: J23.6, U6.11
OSDO6: J27.6, U7.11
OSDO7: J31.6, U8.11
OSDO8: J35.6, U9.11
OSDO9: J39.6, U10.11
OSDO10: J43.6, U11.11
OSDO11: J47.6, U12.11
OSDO12: J51.6, U13.11
OSDO13: J55.6, U14.11
OSDO14: J59.6, U15.11
OSDO15: J63.6, U16.11
OSDO16: J67.6, U17.11
OSDO17: J71.6, U18.11
OSDO18: J75.6, U19.11
OSDO19: J79.6, U20.11
OSDO20: J83.6, U21.11
OSDO21: J87.6, U22.11
OSDO22: J91.6, U23.11
OSDO23: J95.6, U24.11
SCL/SCK: J1.4, J2.4, J4.4, R2.1, U1.13
SCL/SCK1: J5.4, J6.4, J8.4, R8.1, U2.13
SCL/SCK2: J9.4, J10.4, J12.4, R14.1, U3.13
SCL/SCK3: J13.4, J14.4, J16.4, R20.1, U4.13
SCL/SCK4: J17.4, J18.4, J20.4, R26.1, U5.13
SCL/SCK5: J21.4, J22.4, J24.4, R32.1, U6.13
SCL/SCK6: J25.4, J26.4, J28.4, R38.1, U7.13
SCL/SCK7: J29.4, J30.4, J32.4, R44.1, U8.13
SCL/SCK8: J33.4, J34.4, J36.4, R50.1, U9.13
SCL/SCK9: J37.4, J38.4, J40.4, R56.1, U10.13
SCL/SCK10: J41.4, J42.4, J44.4, R62.1, U11.13
SCL/SCK11: J45.4, J46.4, J48.4, R68.1, U12.13
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

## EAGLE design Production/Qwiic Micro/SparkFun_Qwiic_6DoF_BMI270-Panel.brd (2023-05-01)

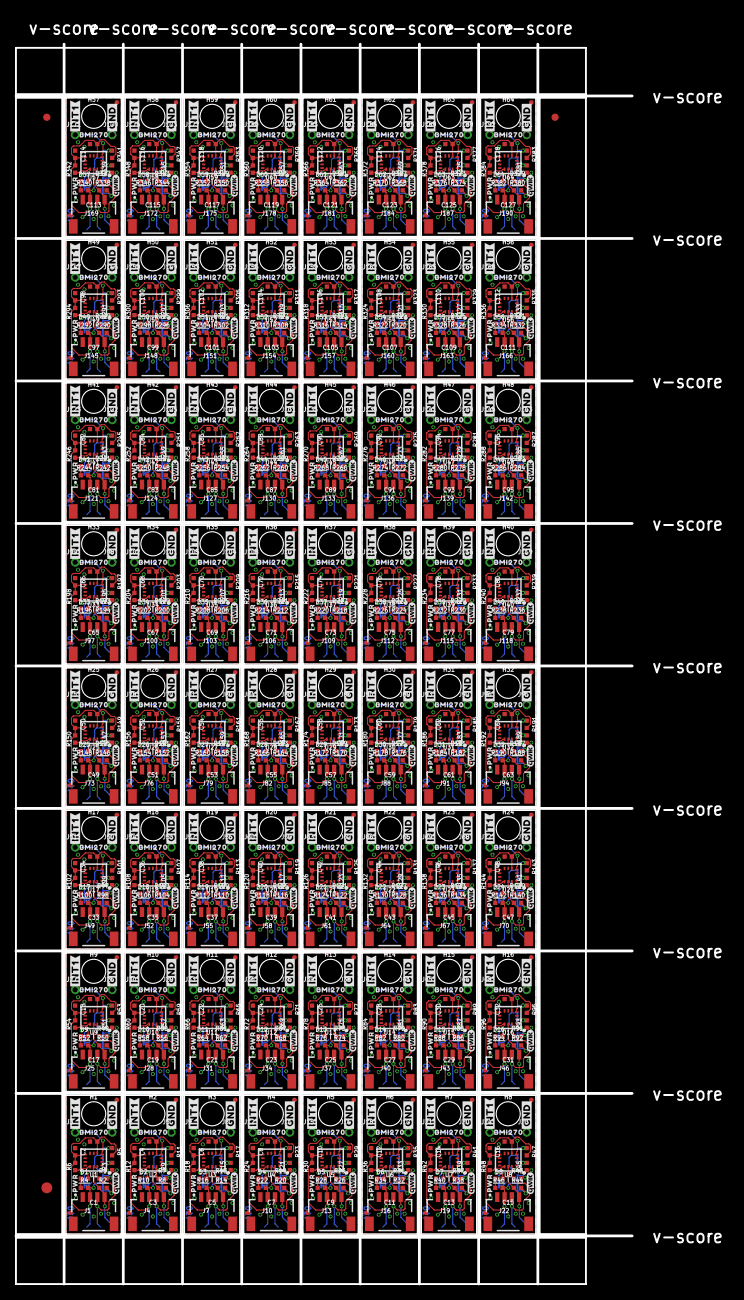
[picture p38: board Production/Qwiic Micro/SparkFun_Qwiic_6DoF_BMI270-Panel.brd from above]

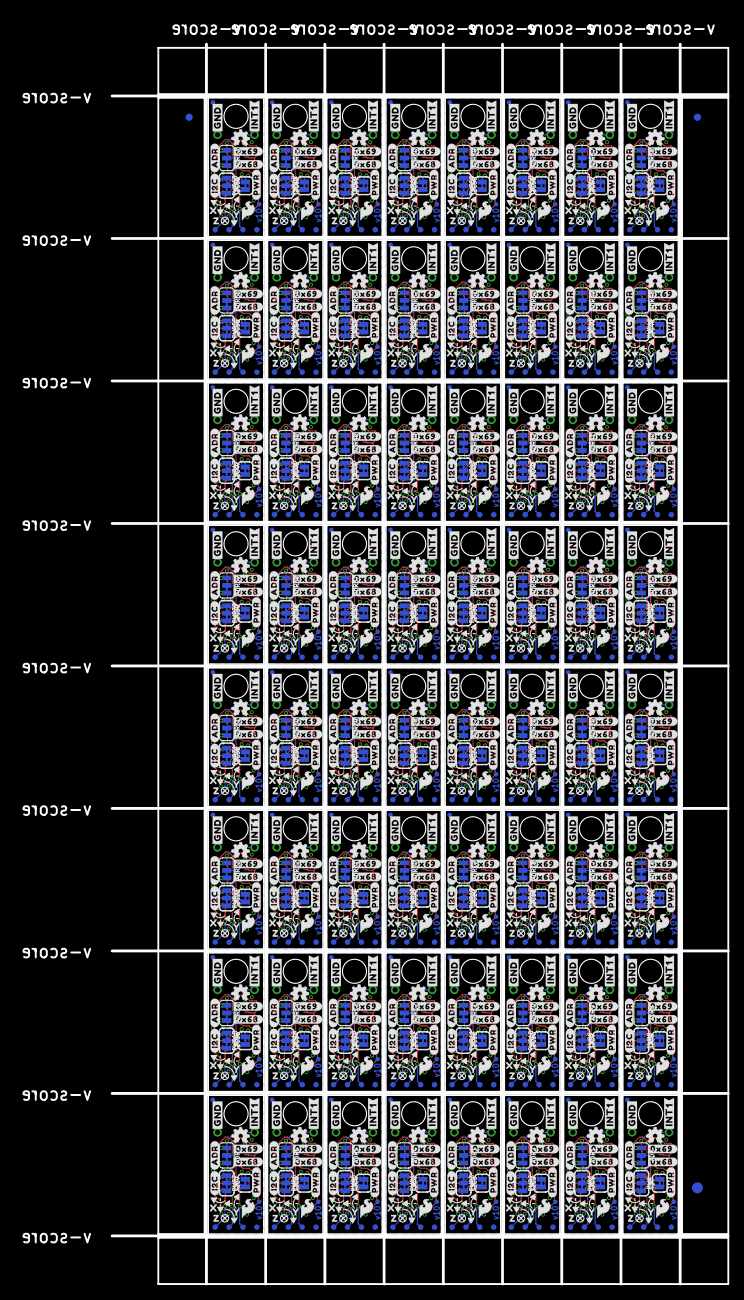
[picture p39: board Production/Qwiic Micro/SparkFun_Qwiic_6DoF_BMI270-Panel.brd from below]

Board: 2 copper layers, 84.6 x 170.2 mm, 2822 parts (1411 on the bottom side), 832 nets.

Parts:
ADR, ADR1, ADR2, ADR3, ADR4, ADR5, ADR6, ADR7, ADR8, ADR9, ADR10, ADR11, ADR12, ADR13, ADR14, ADR15, ADR16, ADR17, ADR18, ADR19, ADR20, ADR21, ADR22, ADR23, ADR24, ADR25, ADR26, ADR27, ADR28, ADR29, ADR30, ADR31, ADR32, ADR33, ADR34, ADR35, ADR36, ADR37, ADR38, ADR39, ADR40, ADR41, ADR42, ADR43, ADR44, ADR45, ADR46, ADR47, ADR48, ADR49, ADR50, ADR51, ADR52, ADR53, ADR54, ADR55, ADR56, ADR57, ADR58, ADR59, ADR60, ADR61, ADR62, ADR63: JUMPER-SMT_3_1-NC_TRACE_SILK; SMT-JUMPER_3_1-NC_TRACE_SILK
C1, C2, C3, C4, C5, C6, C7, C8, C9, C10, C11, C12, C13, C14, C15, C16, C17, C18, C19, C20, C21, C22, C23, C24, C25, C26, C27, C28, C29, C30, C31, C32, C33, C34, C35, C36, C37, C38, C39, C40, C41, C42, C43, C44, C45, C46, C47, C48, C49, C50, C51, C52, C53, C54, C55, C56, C57, C58, C59, C60, C61, C62, C63, C64, C65, C66, C67, C68, C69, C70, C71, C72, C73, C74, C75, C76, C77, C78, C79, C80, C81, C82, C83, C84, C85, C86, C87, C88, C89, C90, C91, C92, C93, C94, C95, C96, C97, C98, C99, C100, C101, C102, C103, C104, C105, C106, C107, C108, C109, C110, C111, C112, C113, C114, C115, C116, C117, C118, C119, C120, C121, C122, C123, C124, C125, C126, C127, C128: 0.1uF; 0402-TIGHT
D1, D2, D3, D4, D5, D6, D7, D8, D9, D10, D11, D12, D13, D14, D15, D16, D17, D18, D19, D20, D21, D22, D23, D24, D25, D26, D27, D28, D29, D30, D31, D32, D33, D34, D35, D36, D37, D38, D39, D40, D41, D42, D43, D44, D45, D46, D47, D48, D49, D50, D51, D52, D53, D54, D55, D56, D57, D58, D59, D60, D61, D62, D63, D64: RED; LED-0402
E$1, E$2, E$3, E$4: FIDUCIAL-1X2
E$5, E$6: FIDUCIAL-1.5X3
FD1, FD2, FD3, FD4, FD5, FD6, FD7, FD8, FD9, FD10, FD11, FD12, FD13, FD14, FD15, FD16, FD17, FD18, FD19, FD20, FD21, FD22, FD23, FD24, FD25, FD26, FD27, FD28, FD29, FD30, FD31, FD32, FD33, FD34, FD35, FD36, FD37, FD38, FD39, FD40, FD41, FD42, FD43, FD44, FD45, FD46, FD47, FD48, FD49, FD50, FD51, FD52, FD53, FD54, FD55, FD56, FD57, FD58, FD59, FD60, FD61, FD62, FD63, FD64, FD65, FD66, FD67, FD68, FD69, FD70, FD71, FD72, FD73, FD74, FD75, FD76, FD77, FD78, FD79, FD80, FD81, FD82, FD83, FD84, FD85, FD86, FD87, FD88, FD89, FD90, FD91, FD92, FD93, FD94, FD95, FD96, FD97, FD98, FD99, FD100, FD101, FD102, FD103, FD104, FD105, FD106, FD107, FD108, FD109, FD110, FD111, FD112, FD113, FD114, FD115, FD116, FD117, FD118, FD119, FD120, FD121, FD122, FD123, FD124, FD125, FD126, FD127, FD128, FD129, FD130, FD131, FD132, FD133, FD134, FD135, FD136, FD137, FD138, FD139, FD140, FD141, FD142, FD143, FD144, FD145, FD146, FD147, FD148, FD149, FD150, FD151, FD152, FD153, FD154, FD155, FD156, FD157, FD158, FD159, FD160, FD161, FD162, FD163, FD164, FD165, FD166, FD167, FD168, FD169, FD170, FD171, FD172, FD173, FD174, FD175, FD176, FD177, FD178, FD179, FD180, FD181, FD182, FD183, FD184, FD185, FD186, FD187, FD188, FD189, FD190, FD191, FD192, FD193, FD194, FD195, FD196, FD197, FD198, FD199, FD200, FD201, FD202, FD203, FD204, FD205, FD206, FD207, FD208, FD209, FD210, FD211, FD212, FD213, FD214, FD215, FD216, FD217, FD218, FD219, FD220, FD221, FD222, FD223, FD224, FD225, FD226, FD227, FD228, FD229, FD230, FD231, FD232, FD233, FD234, FD235, FD236, FD237, FD238, FD239, FD240, FD241, FD242, FD243, FD244, FD245, FD246, FD247, FD248, FD249, FD250, FD251, FD252, FD253, FD254, FD255, FD256: FIDUCIALUFIDUCIAL; FIDUCIAL-MICRO
FRAME1, FRAME2, FRAME3, FRAME4, FRAME5, FRAME6, FRAME7, FRAME8, FRAME9, FRAME10, FRAME11, FRAME12, FRAME13, FRAME14, FRAME15, FRAME16, FRAME17, FRAME18, FRAME19, FRAME20, FRAME21, FRAME22, FRAME23, FRAME24, FRAME25, FRAME26, FRAME27, FRAME28, FRAME29, FRAME30, FRAME31, FRAME32, FRAME33, FRAME34, FRAME35, FRAME36, FRAME37, FRAME38, FRAME39, FRAME40, FRAME41, FRAME42, FRAME43, FRAME44, FRAME45, FRAME46, FRAME47, FRAME48, FRAME49, FRAME50, FRAME51, FRAME52, FRAME53, FRAME54, FRAME55, FRAME56, FRAME57, FRAME58, FRAME59, FRAME60, FRAME61, FRAME62, FRAME63, FRAME64: FRAME-LETTER; CREATIVE_COMMONS
H1, H2, H3, H4, H5, H6, H7, H8, H9, H10, H11, H12, H13, H14, H15, H16, H17, H18, H19, H20, H21, H22, H23, H24, H25, H26, H27, H28, H29, H30, H31, H32, H33, H34, H35, H36, H37, H38, H39, H40, H41, H42, H43, H44, H45, H46, H47, H48, H49, H50, H51, H52, H53, H54, H55, H56, H57, H58, H59, H60, H61, H62, H63, H64: STAND-OFF
I2C, I2C1, I2C2, I2C3, I2C4, I2C5, I2C6, I2C7, I2C8, I2C9, I2C10, I2C11, I2C12, I2C13, I2C14, I2C15, I2C16, I2C17, I2C18, I2C19, I2C20, I2C21, I2C22, I2C23, I2C24, I2C25, I2C26, I2C27, I2C28, I2C29, I2C30, I2C31, I2C32, I2C33, I2C34, I2C35, I2C36, I2C37, I2C38, I2C39, I2C40, I2C41, I2C42, I2C43, I2C44, I2C45, I2C46, I2C47, I2C48, I2C49, I2C50, I2C51, I2C52, I2C53, I2C54, I2C55, I2C56, I2C57, I2C58, I2C59, I2C60, I2C61, I2C62, I2C63: JUMPER-SMT_3_2-NC_TRACE_SILK; SMT-JUMPER_3_2-NC_TRACE_SILK
J1, J4, J7, J10, J13, J16, J19, J22, J25, J28, J31, J34, J37, J40, J43, J46, J49, J52, J55, J58, J61, J64, J67, J70, J73, J76, J79, J82, J85, J88, J91, J94, J97, J100, J103, J106, J109, J112, J115, J118, J121, J124, J127, J130, J133, J136, J139, J142, J145, J148, J151, J154, J157, J160, J163, J166, J169, J172, J175, J178, J181, J184, J187, J190: QWIIC_RIGHT_ANGLE; JST04_1MM_RA
J2, J3, J5, J6, J8, J9, J11, J12, J14, J15, J17, J18, J20, J21, J23, J24, J26, J27, J29, J30, J32, J33, J35, J36, J38, J39, J41, J42, J44, J45, J47, J48, J50, J51, J53, J54, J56, J57, J59, J60, J62, J63, J65, J66, J68, J69, J71, J72, J74, J75, J77, J78, J80, J81, J83, J84, J86, J87, J89, J90, J92, J93, J95, J96, J98, J99, J101, J102, J104, J105, J107, J108, J110, J111, J113, J114, J116, J117, J119, J120, J122, J123, J125, J126, J128, J129, J131, J132, J134, J135, J137, J138, J140, J141, J143, J144, J146, J147, J149, J150, J152, J153, J155, J156, J158, J159, J161, J162, J164, J165, J167, J168, J170, J171, J173, J174, J176, J177, J179, J180, J182, J183, J185, J186, J188, J189, J191, J192: 1X01_1MM_NO_SILK
LOGO1, LOGO4, LOGO7, LOGO10, LOGO13, LOGO16, LOGO19, LOGO22, LOGO25, LOGO28, LOGO31, LOGO34, LOGO37, LOGO40, LOGO43, LOGO46, LOGO49, LOGO52, LOGO55, LOGO58, LOGO61, LOGO64, LOGO67, LOGO70, LOGO73, LOGO76, LOGO79, LOGO82, LOGO85, LOGO88, LOGO91, LOGO94, LOGO97, LOGO100, LOGO103, LOGO106, LOGO109, LOGO112, LOGO115, LOGO118, LOGO121, LOGO124, LOGO127, LOGO130, LOGO133, LOGO136, LOGO139, LOGO142, LOGO145, LOGO148, LOGO151, LOGO154, LOGO157, LOGO160, LOGO163, LOGO166, LOGO169, LOGO172, LOGO175, LOGO178, LOGO181, LOGO184, LOGO187, LOGO190: SFE_LOGO_NAME_FLAMEBLANK; BLANK
LOGO2, LOGO5, LOGO8, LOGO11, LOGO14, LOGO17, LOGO20, LOGO23, LOGO26, LOGO29, LOGO32, LOGO35, LOGO38, LOGO41, LOGO44, LOGO47, LOGO50, LOGO53, LOGO56, LOGO59, LOGO62, LOGO65, LOGO68, LOGO71, LOGO74, LOGO77, LOGO80, LOGO83, LOGO86, LOGO89, LOGO92, LOGO95, LOGO98, LOGO101, LOGO104, LOGO107, LOGO110, LOGO113, LOGO116, LOGO119, LOGO122, LOGO125, LOGO128, LOGO131, LOGO134, LOGO137, LOGO140, LOGO143, LOGO146, LOGO149, LOGO152, LOGO155, LOGO158, LOGO161, LOGO164, LOGO167, LOGO170, LOGO173, LOGO176, LOGO179, LOGO182, LOGO185, LOGO188, LOGO191: QWIIC_LOGO_3MM; QWIIC_3MM
LOGO3, LOGO6, LOGO9, LOGO12, LOGO15, LOGO18, LOGO21, LOGO24, LOGO27, LOGO30, LOGO33, LOGO36, LOGO39, LOGO42, LOGO45, LOGO48, LOGO51, LOGO54, LOGO57, LOGO60, LOGO63, LOGO66, LOGO69, LOGO72, LOGO75, LOGO78, LOGO81, LOGO84, LOGO87, LOGO90, LOGO93, LOGO96, LOGO99, LOGO102, LOGO105, LOGO108, LOGO111, LOGO114, LOGO117, LOGO120, LOGO123, LOGO126, LOGO129, LOGO132, LOGO135, LOGO138, LOGO141, LOGO144, LOGO147, LOGO150, LOGO153, LOGO156, LOGO159, LOGO162, LOGO165, LOGO168, LOGO171, LOGO174, LOGO177, LOGO180, LOGO183, LOGO186, LOGO189, LOGO192: OSHW-LOGOMINI; OSHW-LOGO-MINI
PWR, PWR1, PWR2, PWR3, PWR4, PWR5, PWR6, PWR7, PWR8, PWR9, PWR10, PWR11, PWR12, PWR13, PWR14, PWR15, PWR16, PWR17, PWR18, PWR19, PWR20, PWR21, PWR22, PWR23, PWR24, PWR25, PWR26, PWR27, PWR28, PWR29, PWR30, PWR31, PWR32, PWR33, PWR34, PWR35, PWR36, PWR37, PWR38, PWR39, PWR40, PWR41, PWR42, PWR43, PWR44, PWR45, PWR46, PWR47, PWR48, PWR49, PWR50, PWR51, PWR52, PWR53, PWR54, PWR55, PWR56, PWR57, PWR58, PWR59, PWR60, PWR61, PWR62, PWR63: JUMPER-SMT_2_NC_TRACE_SILK; SMT-JUMPER_2_NC_TRACE_SILK
R1, R2, R7, R8, R13, R14, R19, R20, R25, R26, R31, R32, R37, R38, R43, R44, R49, R50, R55, R56, R61, R62, R67, R68, R73, R74, R79, R80, R85, R86, R91, R92, R97, R98, R103, R104, R109, R110, R115, R116, R121, R122, R127, R128, R133, R134, R139, R140, R145, R146, R151, R152, R157, R158, R163, R164, R169, R170, R175, R176, R181, R182, R187, R188, R193, R194, R199, R200, R205, R206, R211, R212, R217, R218, R223, R224, R229, R230, R235, R236, R241, R242, R247, R248, R253, R254, R259, R260, R265, R266, R271, R272, R277, R278, R283, R284, R289, R290, R295, R296, R301, R302, R307, R308, R313, R314, R319, R320, R325, R326, R331, R332, R337, R338, R343, R344, R349, R350, R355, R356, R361, R362, R367, R368, R373, R374, R379, R380: 2.2k; 0402-TIGHT
R3, R5, R6, R9, R11, R12, R15, R17, R18, R21, R23, R24, R27, R29, R30, R33, R35, R36, R39, R41, R42, R45, R47, R48, R51, R53, R54, R57, R59, R60, R63, R65, R66, R69, R71, R72, R75, R77, R78, R81, R83, R84, R87, R89, R90, R93, R95, R96, R99, R101, R102, R105, R107, R108, R111, R113, R114, R117, R119, R120, R123, R125, R126, R129, R131, R132, R135, R137, R138, R141, R143, R144, R147, R149, R150, R153, R155, R156, R159, R161, R162, R165, R167, R168, R171, R173, R174, R177, R179, R180, R183, R185, R186, R189, R191, R192, R195, R197, R198, R201, R203, R204, R207, R209, R210, R213, R215, R216, R219, R221, R222, R225, R227, R228, R231, R233, R234, R237, R239, R240, R243, R245, R246, R249, R251, R252, R255, R257, R258, R261, R263, R264, R267, R269, R270, R273, R275, R276, R279, R281, R282, R285, R287, R288, R291, R293, R294, R297, R299, R300, R303, R305, R306, R309, R311, R312, R315, R317, R318, R321, R323, R324, R327, R329, R330, R333, R335, R336, R339, R341, R342, R345, R347, R348, R351, R353, R354, R357, R359, R360, R363, R365, R366, R369, R371, R372, R375, R377, R378, R381, R383, R384: 100k; 0402-TIGHT
R4, R10, R16, R22, R28, R34, R40, R46, R52, R58, R64, R70, R76, R82, R88, R94, R100, R106, R112, R118, R124, R130, R136, R142, R148, R154, R160, R166, R172, R178, R184, R190, R196, R202, R208, R214, R220, R226, R232, R238, R244, R250, R256, R262, R268, R274, R280, R286, R292, R298, R304, R310, R316, R322, R328, R334, R340, R346, R352, R358, R364, R370, R376, R382: 4.7k; 0402-TIGHT
TP1, TP2, TP3, TP4, TP5, TP6, TP7, TP8, TP9, TP10, TP11, TP12, TP13, TP14, TP15, TP16, TP17, TP18, TP19, TP20, TP21, TP22, TP23, TP24, TP25, TP26, TP27, TP28, TP29, TP30, TP31, TP32, TP33, TP34, TP35, TP36, TP37, TP38, TP39, TP40, TP41, TP42, TP43, TP44, TP45, TP46, TP47, TP48, TP49, TP50, TP51, TP52, TP53, TP54, TP55, TP56, TP57, TP58, TP59, TP60, TP61, TP62, TP63, TP64, TP65, TP66, TP67, TP68, TP69, TP70, TP71, TP72, TP73, TP74, TP75, TP76, TP77, TP78, TP79, TP80, TP81, TP82, TP83, TP84, TP85, TP86, TP87, TP88, TP89, TP90, TP91, TP92, TP93, TP94, TP95, TP96, TP97, TP98, TP99, TP100, TP101, TP102, TP103, TP104, TP105, TP106, TP107, TP108, TP109, TP110, TP111, TP112, TP113, TP114, TP115, TP116, TP117, TP118, TP119, TP120, TP121, TP122, TP123, TP124, TP125, TP126, TP127, TP128, TP129, TP130, TP131, TP132, TP133, TP134, TP135, TP136, TP137, TP138, TP139, TP140, TP141, TP142, TP143, TP144, TP145, TP146, TP147, TP148, TP149, TP150, TP151, TP152, TP153, TP154, TP155, TP156, TP157, TP158, TP159, TP160, TP161, TP162, TP163, TP164, TP165, TP166, TP167, TP168, TP169, TP170, TP171, TP172, TP173, TP174, TP175, TP176, TP177, TP178, TP179, TP180, TP181, TP182, TP183, TP184, TP185, TP186, TP187, TP188, TP189, TP190, TP191, TP192, TP193, TP194, TP195, TP196, TP197, TP198, TP199, TP200, TP201, TP202, TP203, TP204, TP205, TP206, TP207, TP208, TP209, TP210, TP211, TP212, TP213, TP214, TP215, TP216, TP217, TP218, TP219, TP220, TP221, TP222, TP223, TP224, TP225, TP226, TP227, TP228, TP229, TP230, TP231, TP232, TP233, TP234, TP235, TP236, TP237, TP238, TP239, TP240, TP241, TP242, TP243, TP244, TP245, TP246, TP247, TP248, TP249, TP250, TP251, TP252, TP253, TP254, TP255, TP256: TEST-POINT3; PAD.03X.03
U1, U2, U3, U4, U5, U6, U7, U8, U9, U10, U11, U12, U13, U14, U15, U16, U17, U18, U19, U20, U21, U22, U23, U24, U25, U26, U27, U28, U29, U30, U31, U32, U33, U34, U35, U36, U37, U38, U39, U40, U41, U42, U43, U44, U45, U46, U47, U48, U49, U50, U51, U52, U53, U54, U55, U56, U57, U58, U59, U60, U61, U62, U63, U64: BMI270
U$1, U$10, U$27, U$43, U$58, U$73, U$91, U$106, U$121, U$136, U$151, U$166, U$181, U$196, U$211, U$226, U$241, U$256, U$271, U$286, U$301, U$316, U$331, U$346, U$361, U$376, U$391, U$406, U$421, U$436, U$451, U$466, U$481, U$496, U$511, U$526, U$541, U$556, U$571, U$586, U$601, U$616, U$631, U$646, U$661, U$676, U$691, U$706, U$721, U$736, U$751, U$766, U$781, U$796, U$811, U$826, U$841, U$856, U$871, U$886, U$901, U$916, U$931, U$946: #I2C#0
U$2, U$7, U$22, U$23, U$38, U$39, U$53, U$54, U$68, U$69, U$86, U$87, U$101, U$102, U$116, U$117, U$131, U$132, U$146, U$147, U$161, U$162, U$176, U$177, U$191, U$192, U$206, U$207, U$221, U$222, U$236, U$237, U$251, U$252, U$266, U$267, U$281, U$282, U$296, U$297, U$311, U$312, U$326, U$327, U$341, U$342, U$356, U$357, U$371, U$372, U$386, U$387, U$401, U$402, U$416, U$417, U$431, U$432, U$446, U$447, U$461, U$462, U$476, U$477, U$491, U$492, U$506, U$507, U$521, U$522, U$536, U$537, U$551, U$552, U$566, U$567, U$581, U$582, U$596, U$597, U$611, U$612, U$626, U$627, U$641, U$642, U$656, U$657, U$671, U$672, U$686, U$687, U$701, U$702, U$716, U$717, U$731, U$732, U$746, U$747, U$761, U$762, U$776, U$777, U$791, U$792, U$806, U$807, U$821, U$822, U$836, U$837, U$851, U$852, U$866, U$867, U$881, U$882, U$896, U$897, U$911, U$912, U$926, U$927, U$941, U$942, U$956, U$957: #GND#0
U$3, U$26, U$42, U$57, U$72, U$90, U$105, U$120, U$135, U$150, U$165, U$180, U$195, U$210, U$225, U$240, U$255, U$270, U$285, U$300, U$315, U$330, U$345, U$360, U$375, U$390, U$405, U$420, U$435, U$450, U$465, U$480, U$495, U$510, U$525, U$540, U$555, U$570, U$585, U$600, U$615, U$630, U$645, U$660, U$675, U$690, U$705, U$720, U$735, U$750, U$765, U$780, U$795, U$810, U$825, U$840, U$855, U$870, U$885, U$900, U$915, U$930, U$945, U$960: SFE_LOGO_FLAME_.1
U$4, U$11, U$28, U$44, U$59, U$74, U$92, U$107, U$122, U$137, U$152, U$167, U$182, U$197, U$212, U$227, U$242, U$257, U$272, U$287, U$302, U$317, U$332, U$347, U$362, U$377, U$392, U$407, U$422, U$437, U$452, U$467, U$482, U$497, U$512, U$527, U$542, U$557, U$572, U$587, U$602, U$617, U$632, U$647, U$662, U$677, U$692, U$707, U$722, U$737, U$752, U$767, U$782, U$797, U$812, U$827, U$842, U$857, U$872, U$887, U$902, U$917, U$932, U$947: #PWR#0
U$5, U$12, U$29, U$45, U$60, U$75, U$93, U$108, U$123, U$138, U$153, U$168, U$183, U$198, U$213, U$228, U$243, U$258, U$273, U$288, U$303, U$318, U$333, U$348, U$363, U$378, U$393, U$408, U$423, U$438, U$453, U$468, U$483, U$498, U$513, U$528, U$543, U$558, U$573, U$588, U$603, U$618, U$633, U$648, U$663, U$678, U$693, U$708, U$723, U$738, U$753, U$768, U$783, U$798, U$813, U$828, U$843, U$858, U$873, U$888, U$903, U$918, U$933, U$948: #ADR#0
U$6, U$13, U$30, U$46, U$61, U$76, U$94, U$109, U$124, U$139, U$154, U$169, U$184, U$199, U$214, U$229, U$244, U$259, U$274, U$289, U$304, U$319, U$334, U$349, U$364, U$379, U$394, U$409, U$424, U$439, U$454, U$469, U$484, U$499, U$514, U$529, U$544, U$559, U$574, U$589, U$604, U$619, U$634, U$649, U$664, U$679, U$694, U$709, U$724, U$739, U$754, U$769, U$784, U$799, U$814, U$829, U$844, U$859, U$874, U$889, U$904, U$919, U$934, U$949: #0X68#0
U$8, U$9, U$24, U$25, U$40, U$41, U$55, U$56, U$70, U$71, U$88, U$89, U$103, U$104, U$118, U$119, U$133, U$134, U$148, U$149, U$163, U$164, U$178, U$179, U$193, U$194, U$208, U$209, U$223, U$224, U$238, U$239, U$253, U$254, U$268, U$269, U$283, U$284, U$298, U$299, U$313, U$314, U$328, U$329, U$343, U$344, U$358, U$359, U$373, U$374, U$388, U$389, U$403, U$404, U$418, U$419, U$433, U$434, U$448, U$449, U$463, U$464, U$478, U$479, U$493, U$494, U$508, U$509, U$523, U$524, U$538, U$539, U$553, U$554, U$568, U$569, U$583, U$584, U$598, U$599, U$613, U$614, U$628, U$629, U$643, U$644, U$658, U$659, U$673, U$674, U$688, U$689, U$703, U$704, U$718, U$719, U$733, U$734, U$748, U$749, U$763, U$764, U$778, U$779, U$793, U$794, U$808, U$809, U$823, U$824, U$838, U$839, U$853, U$854, U$868, U$869, U$883, U$884, U$898, U$899, U$913, U$914, U$928, U$929, U$943, U$944, U$958, U$959: #INT1#0
U$14, U$18, U$31, U$47, U$62, U$77, U$95, U$110, U$125, U$140, U$155, U$170, U$185, U$200, U$215, U$230, U$245, U$260, U$275, U$290, U$305, U$320, U$335, U$350, U$365, U$380, U$395, U$410, U$425, U$440, U$455, U$470, U$485, U$500, U$515, U$530, U$545, U$560, U$575, U$590, U$605, U$620, U$635, U$650, U$665, U$680, U$695, U$710, U$725, U$740, U$755, U$770, U$785, U$800, U$815, U$830, U$845, U$860, U$875, U$890, U$905, U$920, U$935, U$950: #0X69#0
U$15, U$21, U$32, U$48, U$63, U$78, U$96, U$111, U$126, U$141, U$156, U$171, U$186, U$201, U$216, U$231, U$246, U$261, U$276, U$291, U$306, U$321, U$336, U$351, U$366, U$381, U$396, U$411, U$426, U$441, U$456, U$471, U$486, U$501, U$516, U$531, U$546, U$561, U$576, U$591, U$606, U$621, U$636, U$651, U$666, U$681, U$696, U$711, U$726, U$741, U$756, U$771, U$786, U$801, U$816, U$831, U$846, U$861, U$876, U$891, U$906, U$921, U$936, U$951: BMI2700
U$16, U$33, U$49, U$64, U$79, U$82, U$97, U$112, U$127, U$142, U$157, U$172, U$187, U$202, U$217, U$232, U$247, U$262, U$277, U$292, U$307, U$322, U$337, U$352, U$367, U$382, U$397, U$412, U$427, U$442, U$457, U$472, U$487, U$502, U$517, U$532, U$547, U$562, U$577, U$592, U$607, U$622, U$637, U$652, U$667, U$682, U$697, U$712, U$727, U$742, U$757, U$772, U$787, U$802, U$817, U$832, U$847, U$862, U$877, U$892, U$907, U$922, U$937, U$952: X0
U$17, U$35, U$50, U$65, U$80, U$83, U$98, U$113, U$128, U$143, U$158, U$173, U$188, U$203, U$218, U$233, U$248, U$263, U$278, U$293, U$308, U$323, U$338, U$353, U$368, U$383, U$398, U$413, U$428, U$443, U$458, U$473, U$488, U$503, U$518, U$533, U$548, U$563, U$578, U$593, U$608, U$623, U$638, U$653, U$668, U$683, U$698, U$713, U$728, U$743, U$758, U$773, U$788, U$803, U$818, U$833, U$848, U$863, U$878, U$893, U$908, U$923, U$938, U$953: Y0
U$19, U$36, U$51, U$66, U$81, U$84, U$99, U$114, U$129, U$144, U$159, U$174, U$189, U$204, U$219, U$234, U$249, U$264, U$279, U$294, U$309, U$324, U$339, U$354, U$369, U$384, U$399, U$414, U$429, U$444, U$459, U$474, U$489, U$504, U$519, U$534, U$549, U$564, U$579, U$594, U$609, U$624, U$639, U$654, U$669, U$684, U$699, U$714, U$729, U$744, U$759, U$774, U$789, U$804, U$819, U$834, U$849, U$864, U$879, U$894, U$909, U$924, U$939, U$954: Z0
U$20, U$34, U$37, U$52, U$67, U$85, U$100, U$115, U$130, U$145, U$160, U$175, U$190, U$205, U$220, U$235, U$250, U$265, U$280, U$295, U$310, U$325, U$340, U$355, U$370, U$385, U$400, U$415, U$430, U$445, U$460, U$475, U$490, U$505, U$520, U$535, U$550, U$565, U$580, U$595, U$610, U$625, U$640, U$655, U$670, U$685, U$700, U$715, U$730, U$745, U$760, U$775, U$790, U$805, U$820, U$835, U$850, U$865, U$880, U$895, U$910, U$925, U$940, U$955: PWR0

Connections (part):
3.3V: C1.2, C2.2, I2C.2, J1.2, R4.2, R5.2, R6.2, TP3.1, U1.5, U1.8
3.3V1: C3.2, C4.2, I2C1.2, J4.2, R10.2, R11.2, R12.2, TP7.1, U2.5, U2.8
3.3V2: C5.2, C6.2, I2C2.2, J7.2, R16.2, R17.2, R18.2, TP11.1, U3.5, U3.8
3.3V3: C7.2, C8.2, I2C3.2, J10.2, R22.2, R23.2, R24.2, TP15.1, U4.5, U4.8
3.3V4: C9.2, C10.2, I2C4.2, J13.2, R28.2, R29.2, R30.2, TP19.1, U5.5, U5.8
3.3V5: C11.2, C12.2, I2C5.2, J16.2, R34.2, R35.2, R36.2, TP23.1, U6.5, U6.8
3.3V6: C13.2, C14.2, I2C6.2, J19.2, R40.2, R41.2, R42.2, TP27.1, U7.5, U7.8
3.3V7: C15.2, C16.2, I2C7.2, J22.2, R46.2, R47.2, R48.2, TP31.1, U8.5, U8.8
3.3V8: C17.2, C18.2, I2C8.2, J25.2, R52.2, R53.2, R54.2, TP35.1, U9.5, U9.8
3.3V9: C19.2, C20.2, I2C9.2, J28.2, R58.2, R59.2, R60.2, TP39.1, U10.5, U10.8
3.3V10: C21.2, C22.2, I2C10.2, J31.2, R64.2, R65.2, R66.2, TP43.1, U11.5, U11.8
3.3V11: C23.2, C24.2, I2C11.2, J34.2, R70.2, R71.2, R72.2, TP47.1, U12.5, U12.8
3.3V12: C25.2, C26.2, I2C12.2, J37.2, R76.2, R77.2, R78.2, TP51.1, U13.5, U13.8
3.3V13: C27.2, C28.2, I2C13.2, J40.2, R82.2, R83.2, R84.2, TP55.1, U14.5, U14.8
3.3V14: C29.2, C30.2, I2C14.2, J43.2, R88.2, R89.2, R90.2, TP59.1, U15.5, U15.8
3.3V15: C31.2, C32.2, I2C15.2, J46.2, R94.2, R95.2, R96.2, TP63.1, U16.5, U16.8
3.3V16: C33.2, C34.2, I2C16.2, J49.2, R100.2, R101.2, R102.2, TP67.1, U17.5, U17.8
3.3V17: C35.2, C36.2, I2C17.2, J52.2, R106.2, R107.2, R108.2, TP71.1, U18.5, U18.8
3.3V18: C37.2, C38.2, I2C18.2, J55.2, R112.2, R113.2, R114.2, TP75.1, U19.5, U19.8
3.3V19: C39.2, C40.2, I2C19.2, J58.2, R118.2, R119.2, R120.2, TP79.1, U20.5, U20.8
3.3V20: C41.2, C42.2, I2C20.2, J61.2, R124.2, R125.2, R126.2, TP83.1, U21.5, U21.8
3.3V21: C43.2, C44.2, I2C21.2, J64.2, R130.2, R131.2, R132.2, TP87.1, U22.5, U22.8
3.3V22: C45.2, C46.2, I2C22.2, J67.2, R136.2, R137.2, R138.2, TP91.1, U23.5, U23.8
3.3V23: C47.2, C48.2, I2C23.2, J70.2, R142.2, R143.2, R144.2, TP95.1, U24.5, U24.8
3.3V24: C49.2, C50.2, I2C24.2, J73.2, R148.2, R149.2, R150.2, TP99.1, U25.5, U25.8
3.3V25: C51.2, C52.2, I2C25.2, J76.2, R154.2, R155.2, R156.2, TP103.1, U26.5, U26.8
3.3V26: C53.2, C54.2, I2C26.2, J79.2, R160.2, R161.2, R162.2, TP107.1, U27.5, U27.8
3.3V27: C55.2, C56.2, I2C27.2, J82.2, R166.2, R167.2, R168.2, TP111.1, U28.5, U28.8
3.3V28: C57.2, C58.2, I2C28.2, J85.2, R172.2, R173.2, R174.2, TP115.1, U29.5, U29.8
3.3V29: C59.2, C60.2, I2C29.2, J88.2, R178.2, R179.2, R180.2, TP119.1, U30.5, U30.8
3.3V30: C61.2, C62.2, I2C30.2, J91.2, R184.2, R185.2, R186.2, TP123.1, U31.5, U31.8
3.3V31: C63.2, C64.2, I2C31.2, J94.2, R190.2, R191.2, R192.2, TP127.1, U32.5, U32.8
3.3V32: C65.2, C66.2, I2C32.2, J97.2, R196.2, R197.2, R198.2, TP131.1, U33.5, U33.8
3.3V33: C67.2, C68.2, I2C33.2, J100.2, R202.2, R203.2, R204.2, TP135.1, U34.5, U34.8
3.3V34: C69.2, C70.2, I2C34.2, J103.2, R208.2, R209.2, R210.2, TP139.1, U35.5, U35.8
3.3V35: C71.2, C72.2, I2C35.2, J106.2, R214.2, R215.2, R216.2, TP143.1, U36.5, U36.8
3.3V36: C73.2, C74.2, I2C36.2, J109.2, R220.2, R221.2, R222.2, TP147.1, U37.5, U37.8
3.3V37: C75.2, C76.2, I2C37.2, J112.2, R226.2, R227.2, R228.2, TP151.1, U38.5, U38.8
3.3V38: C77.2, C78.2, I2C38.2, J115.2, R232.2, R233.2, R234.2, TP155.1, U39.5, U39.8
3.3V39: C79.2, C80.2, I2C39.2, J118.2, R238.2, R239.2, R240.2, TP159.1, U40.5, U40.8
3.3V40: C81.2, C82.2, I2C40.2, J121.2, R244.2, R245.2, R246.2, TP163.1, U41.5, U41.8
3.3V41: C83.2, C84.2, I2C41.2, J124.2, R250.2, R251.2, R252.2, TP167.1, U42.5, U42.8
3.3V42: C85.2, C86.2, I2C42.2, J127.2, R256.2, R257.2, R258.2, TP171.1, U43.5, U43.8
3.3V43: C87.2, C88.2, I2C43.2, J130.2, R262.2, R263.2, R264.2, TP175.1, U44.5, U44.8
3.3V44: C89.2, C90.2, I2C44.2, J133.2, R268.2, R269.2, R270.2, TP179.1, U45.5, U45.8
3.3V45: C91.2, C92.2, I2C45.2, J136.2, R274.2, R275.2, R276.2, TP183.1, U46.5, U46.8
3.3V46: C93.2, C94.2, I2C46.2, J139.2, R280.2, R281.2, R282.2, TP187.1, U47.5, U47.8
3.3V47: C95.2, C96.2, I2C47.2, J142.2, R286.2, R287.2, R288.2, TP191.1, U48.5, U48.8
3.3V48: C97.2, C98.2, I2C48.2, J145.2, R292.2, R293.2, R294.2, TP195.1, U49.5, U49.8
3.3V49: C99.2, C100.2, I2C49.2, J148.2, R298.2, R299.2, R300.2, TP199.1, U50.5, U50.8
3.3V50: C101.2, C102.2, I2C50.2, J151.2, R304.2, R305.2, R306.2, TP203.1, U51.5, U51.8
3.3V51: C103.2, C104.2, I2C51.2, J154.2, R310.2, R311.2, R312.2, TP207.1, U52.5, U52.8
3.3V52: C105.2, C106.2, I2C52.2, J157.2, R316.2, R317.2, R318.2, TP211.1, U53.5, U53.8
3.3V53: C107.2, C108.2, I2C53.2, J160.2, R322.2, R323.2, R324.2, TP215.1, U54.5, U54.8
3.3V54: C109.2, C110.2, I2C54.2, J163.2, R328.2, R329.2, R330.2, TP219.1, U55.5, U55.8
3.3V55: C111.2, C112.2, I2C55.2, J166.2, R334.2, R335.2, R336.2, TP223.1, U56.5, U56.8
3.3V56: C113.2, C114.2, I2C56.2, J169.2, R340.2, R341.2, R342.2, TP227.1, U57.5, U57.8
3.3V57: C115.2, C116.2, I2C57.2, J172.2, R346.2, R347.2, R348.2, TP231.1, U58.5, U58.8
3.3V58: C117.2, C118.2, I2C58.2, J175.2, R352.2, R353.2, R354.2, TP235.1, U59.5, U59.8
3.3V59: C119.2, C120.2, I2C59.2, J178.2, R358.2, R359.2, R360.2, TP239.1, U60.5, U60.8
3.3V60: C121.2, C122.2, I2C60.2, J181.2, R364.2, R365.2, R366.2, TP243.1, U61.5, U61.8
3.3V61: C123.2, C124.2, I2C61.2, J184.2, R370.2, R371.2, R372.2, TP247.1, U62.5, U62.8
3.3V62: C125.2, C126.2, I2C62.2, J187.2, R376.2, R377.2, R378.2, TP251.1, U63.5, U63.8
3.3V63: C127.2, C128.2, I2C63.2, J190.2, R382.2, R383.2, R384.2, TP255.1, U64.5, U64.8
ADR: ADR.2, U1.1
ADR1: ADR1.2, U2.1
ADR2: ADR2.2, U3.1
ADR3: ADR3.2, U4.1
ADR4: ADR4.2, U5.1
ADR5: ADR5.2, U6.1
ADR6: ADR6.2, U7.1
ADR7: ADR7.2, U8.1
ADR8: ADR8.2, U9.1
ADR9: ADR9.2, U10.1
ADR10: ADR10.2, U11.1
ADR11: ADR11.2, U12.1
ADR12: ADR12.2, U13.1
ADR13: ADR13.2, U14.1
ADR14: ADR14.2, U15.1
ADR15: ADR15.2, U16.1
ADR16: ADR16.2, U17.1
ADR17: ADR17.2, U18.1
ADR18: ADR18.2, U19.1
ADR19: ADR19.2, U20.1
ADR20: ADR20.2, U21.1
ADR21: ADR21.2, U22.1
ADR22: ADR22.2, U23.1
ADR23: ADR23.2, U24.1
ADR24: ADR24.2, U25.1
ADR25: ADR25.2, U26.1
ADR26: ADR26.2, U27.1
ADR27: ADR27.2, U28.1
ADR28: ADR28.2, U29.1
ADR29: ADR29.2, U30.1
ADR30: ADR30.2, U31.1
ADR31: ADR31.2, U32.1
ADR32: ADR32.2, U33.1
ADR33: ADR33.2, U34.1
ADR34: ADR34.2, U35.1
ADR35: ADR35.2, U36.1
ADR36: ADR36.2, U37.1
ADR37: ADR37.2, U38.1
ADR38: ADR38.2, U39.1
ADR39: ADR39.2, U40.1
ADR40: ADR40.2, U41.1
ADR41: ADR41.2, U42.1
ADR42: ADR42.2, U43.1
ADR43: ADR43.2, U44.1
ADR44: ADR44.2, U45.1
ADR45: ADR45.2, U46.1
ADR46: ADR46.2, U47.1
ADR47: ADR47.2, U48.1
ADR48: ADR48.2, U49.1
ADR49: ADR49.2, U50.1
ADR50: ADR50.2, U51.1
ADR51: ADR51.2, U52.1
ADR52: ADR52.2, U53.1
ADR53: ADR53.2, U54.1
ADR54: ADR54.2, U55.1
ADR55: ADR55.2, U56.1
ADR56: ADR56.2, U57.1
ADR57: ADR57.2, U58.1
ADR58: ADR58.2, U59.1
ADR59: ADR59.2, U60.1
ADR60: ADR60.2, U61.1
ADR61: ADR61.2, U62.1
ADR62: ADR62.2, U63.1
ADR63: ADR63.2, U64.1
GND: C1.1, C2.1, J1.1, J2.1, PWR.1, R3.1, TP4.1, U1.6, U1.7
GND1: C3.1, C4.1, J4.1, J5.1, PWR1.1, R9.1, TP8.1, U2.6, U2.7
GND2: C5.1, C6.1, J7.1, J8.1, PWR2.1, R15.1, TP12.1, U3.6, U3.7
GND3: C7.1, C8.1, J10.1, J11.1, PWR3.1, R21.1, TP16.1, U4.6, U4.7
GND4: C9.1, C10.1, J13.1, J14.1, PWR4.1, R27.1, TP20.1, U5.6, U5.7
GND5: C11.1, C12.1, J16.1, J17.1, PWR5.1, R33.1, TP24.1, U6.6, U6.7
GND6: C13.1, C14.1, J19.1, J20.1, PWR6.1, R39.1, TP28.1, U7.6, U7.7
GND7: C15.1, C16.1, J22.1, J23.1, PWR7.1, R45.1, TP32.1, U8.6, U8.7
GND8: C17.1, C18.1, J25.1, J26.1, PWR8.1, R51.1, TP36.1, U9.6, U9.7
GND9: C19.1, C20.1, J28.1, J29.1, PWR9.1, R57.1, TP40.1, U10.6, U10.7
GND10: C21.1, C22.1, J31.1, J32.1, PWR10.1, R63.1, TP44.1, U11.6, U11.7
GND11: C23.1, C24.1, J34.1, J35.1, PWR11.1, R69.1, TP48.1, U12.6, U12.7
GND12: C25.1, C26.1, J37.1, J38.1, PWR12.1, R75.1, TP52.1, U13.6, U13.7
GND13: C27.1, C28.1, J40.1, J41.1, PWR13.1, R81.1, TP56.1, U14.6, U14.7
GND14: C29.1, C30.1, J43.1, J44.1, PWR14.1, R87.1, TP60.1, U15.6, U15.7
GND15: C31.1, C32.1, J46.1, J47.1, PWR15.1, R93.1, TP64.1, U16.6, U16.7
GND16: C33.1, C34.1, J49.1, J50.1, PWR16.1, R99.1, TP68.1, U17.6, U17.7
GND17: C35.1, C36.1, J52.1, J53.1, PWR17.1, R105.1, TP72.1, U18.6, U18.7
GND18: C37.1, C38.1, J55.1, J56.1, PWR18.1, R111.1, TP76.1, U19.6, U19.7
GND19: C39.1, C40.1, J58.1, J59.1, PWR19.1, R117.1, TP80.1, U20.6, U20.7
GND20: C41.1, C42.1, J61.1, J62.1, PWR20.1, R123.1, TP84.1, U21.6, U21.7
GND21: C43.1, C44.1, J64.1, J65.1, PWR21.1, R129.1, TP88.1, U22.6, U22.7
GND22: C45.1, C46.1, J67.1, J68.1, PWR22.1, R135.1, TP92.1, U23.6, U23.7
GND23: C47.1, C48.1, J70.1, J71.1, PWR23.1, R141.1, TP96.1, U24.6, U24.7
GND24: C49.1, C50.1, J73.1, J74.1, PWR24.1, R147.1, TP100.1, U25.6, U25.7
GND25: C51.1, C52.1, J76.1, J77.1, PWR25.1, R153.1, TP104.1, U26.6, U26.7
GND26: C53.1, C54.1, J79.1, J80.1, PWR26.1, R159.1, TP108.1, U27.6, U27.7
GND27: C55.1, C56.1, J82.1, J83.1, PWR27.1, R165.1, TP112.1, U28.6, U28.7
GND28: C57.1, C58.1, J85.1, J86.1, PWR28.1, R171.1, TP116.1, U29.6, U29.7
GND29: C59.1, C60.1, J88.1, J89.1, PWR29.1, R177.1, TP120.1, U30.6, U30.7
GND30: C61.1, C62.1, J91.1, J92.1, PWR30.1, R183.1, TP124.1, U31.6, U31.7
GND31: C63.1, C64.1, J94.1, J95.1, PWR31.1, R189.1, TP128.1, U32.6, U32.7
GND32: C65.1, C66.1, J97.1, J98.1, PWR32.1, R195.1, TP132.1, U33.6, U33.7
GND33: C67.1, C68.1, J100.1, J101.1, PWR33.1, R201.1, TP136.1, U34.6, U34.7
GND34: C69.1, C70.1, J103.1, J104.1, PWR34.1, R207.1, TP140.1, U35.6, U35.7
GND35: C71.1, C72.1, J106.1, J107.1, PWR35.1, R213.1, TP144.1, U36.6, U36.7
GND36: C73.1, C74.1, J109.1, J110.1, PWR36.1, R219.1, TP148.1, U37.6, U37.7
GND37: C75.1, C76.1, J112.1, J113.1, PWR37.1, R225.1, TP152.1, U38.6, U38.7
GND38: C77.1, C78.1, J115.1, J116.1, PWR38.1, R231.1, TP156.1, U39.6, U39.7
GND39: C79.1, C80.1, J118.1, J119.1, PWR39.1, R237.1, TP160.1, U40.6, U40.7
GND40: C81.1, C82.1, J121.1, J122.1, PWR40.1, R243.1, TP164.1, U41.6, U41.7
GND41: C83.1, C84.1, J124.1, J125.1, PWR41.1, R249.1, TP168.1, U42.6, U42.7
GND42: C85.1, C86.1, J127.1, J128.1, PWR42.1, R255.1, TP172.1, U43.6, U43.7
GND43: C87.1, C88.1, J130.1, J131.1, PWR43.1, R261.1, TP176.1, U44.6, U44.7
GND44: C89.1, C90.1, J133.1, J134.1, PWR44.1, R267.1, TP180.1, U45.6, U45.7
GND45: C91.1, C92.1, J136.1, J137.1, PWR45.1, R273.1, TP184.1, U46.6, U46.7
GND46: C93.1, C94.1, J139.1, J140.1, PWR46.1, R279.1, TP188.1, U47.6, U47.7
GND47: C95.1, C96.1, J142.1, J143.1, PWR47.1, R285.1, TP192.1, U48.6, U48.7
GND48: C97.1, C98.1, J145.1, J146.1, PWR48.1, R291.1, TP196.1, U49.6, U49.7
GND49: C99.1, C100.1, J148.1, J149.1, PWR49.1, R297.1, TP200.1, U50.6, U50.7
GND50: C101.1, C102.1, J151.1, J152.1, PWR50.1, R303.1, TP204.1, U51.6, U51.7
GND51: C103.1, C104.1, J154.1, J155.1, PWR51.1, R309.1, TP208.1, U52.6, U52.7
GND52: C105.1, C106.1, J157.1, J158.1, PWR52.1, R315.1, TP212.1, U53.6, U53.7
GND53: C107.1, C108.1, J160.1, J161.1, PWR53.1, R321.1, TP216.1, U54.6, U54.7
GND54: C109.1, C110.1, J163.1, J164.1, PWR54.1, R327.1, TP220.1, U55.6, U55.7
GND55: C111.1, C112.1, J166.1, J167.1, PWR55.1, R333.1, TP224.1, U56.6, U56.7
GND56: C113.1, C114.1, J169.1, J170.1, PWR56.1, R339.1, TP228.1, U57.6, U57.7
GND57: C115.1, C116.1, J172.1, J173.1, PWR57.1, R345.1, TP232.1, U58.6, U58.7
GND58: C117.1, C118.1, J175.1, J176.1, PWR58.1, R351.1, TP236.1, U59.6, U59.7
GND59: C119.1, C120.1, J178.1, J179.1, PWR59.1, R357.1, TP240.1, U60.6, U60.7
GND60: C121.1, C122.1, J181.1, J182.1, PWR60.1, R363.1, TP244.1, U61.6, U61.7
GND61: C123.1, C124.1, J184.1, J185.1, PWR61.1, R369.1, TP248.1, U62.6, U62.7
GND62: C125.1, C126.1, J187.1, J188.1, PWR62.1, R375.1, TP252.1, U63.6, U63.7
GND63: C127.1, C128.1, J190.1, J191.1, PWR63.1, R381.1, TP256.1, U64.6, U64.7
INT1: J3.1, U1.4
INT2: J6.1, U2.4
INT3: J9.1, U3.4
INT4: J12.1, U4.4
INT5: J15.1, U5.4
INT6: J18.1, U6.4
INT7: J21.1, U7.4
INT8: J24.1, U8.4
INT9: J27.1, U9.4
INT10: J30.1, U10.4
INT11: J33.1, U11.4
INT12: J36.1, U12.4
INT13: J39.1, U13.4
INT14: J42.1, U14.4
INT15: J45.1, U15.4
INT16: J48.1, U16.4
INT17: J51.1, U17.4
INT18: J54.1, U18.4
INT19: J57.1, U19.4
INT20: J60.1, U20.4
INT21: J63.1, U21.4
INT22: J66.1, U22.4
INT23: J69.1, U23.4
INT24: J72.1, U24.4
INT25: J75.1, U25.4
INT26: J78.1, U26.4
INT27: J81.1, U27.4
INT28: J84.1, U28.4
INT29: J87.1, U29.4
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

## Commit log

2023-04-26 Add SparkX Eagle files
    [Qwiic_BMI270.brd, Qwiic_BMI270.sch]
2023-04-26 Add BMI270 library file
    Also replace part in sch/brd files with new library part
    [Qwiic_BMI270.brd, Qwiic_BMI270.sch]
2023-04-26 v10 updates
    Bump version number to v10
    Rename sch/brd files
    Move files into "1x1" folder in preparation for adding Qwiic Micro design
    Schematic:
    Update schematic frame
    Add "revised by"
    Change all text to vector font
    Change section separator lines to dashed on info layer
    Move I2C pullups and I2C address selection to dedicated sections
    Give C1 dedicated power symbols
    Add second decoupling cap for other 3V3 pin
    Replace R3 with 100k for lower power consumption
    Replace ADR jumper with 3-way jumper
    Add pullup resistor to CS net
    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
    [Qwiic_BMI270.brd, Qwiic_BMI270.sch, SparkFun_Qwiic_6DoF_BMI270.brd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]
2023-04-26 Fix vector fonts in schematic
    Old schematic had residual things from years ago causing schematic auto checklist to give warning about vector font. Just copied into new schematic to fix
    Also smashed power symbols to make power symbols use vector font
    [SparkFun_Qwiic_6DoF_BMI270.sch]
2023-04-27 Checklist updates
    Change max VDD to VDD range
    Add ordering instructions
    Add axis labels to bottom silk
    Add silk label to power LED
    [SparkFun_Qwiic_6DoF_BMI270.brd, SparkFun_Qwiic_6DoF_BMI270.sch]
2023-04-27 Add Qwiic Micro version
    [SparkFun_Qwiic_6DoF_BMI270.brd, SparkFun_Qwiic_6DoF_BMI270.sch]
2023-05-01 Design review updates
    Qwiic 1x1:
    Add y position of headers to measures
    Nudge I2C vias under right Qwiic connector
    Nudge vias away from silk
    Qwiic Micro:
    Remove traces and vias under chip
    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
    [SparkFun_Qwiic_6DoF_BMI270.brd]
2023-05-01 Add "default" to I2C address in schematics
    [SparkFun_Qwiic_6DoF_BMI270.sch]
2023-05-01 Design review updates
    Add gap to linear axis silk to clarify gyro directions
    Add GND via to Qwiic Micro
    [SparkFun_Qwiic_6DoF_BMI270.brd]
2023-05-01 Silk tweaks
    Add silk lines between passive components
    Nudge "BMI270" silk on Qwiic Micro
    Add bigger pin 1 indicator dot to Qwiic Micro
    [SparkFun_Qwiic_6DoF_BMI270.brd]
2023-05-01 Add production files
    [SparkFun_Qwiic_6DoF_BMI270-Panel.GBL, SparkFun_Qwiic_6DoF_BMI270-Panel.GBP, SparkFun_Qwiic_6DoF_BMI270-Panel.GBS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]
2023-05-01 Remove PROD_ID from headers of 1x1
    [SparkFun_Qwiic_6DoF_BMI270-Panel.brd, SparkFun_Qwiic_6DoF_BMI270.brd, SparkFun_Qwiic_6DoF_BMI270.sch]
2023-06-13 Updating contribute page links and required materials
2023-06-22 Testing framework changes

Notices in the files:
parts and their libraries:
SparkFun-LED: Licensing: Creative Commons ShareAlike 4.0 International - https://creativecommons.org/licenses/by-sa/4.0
